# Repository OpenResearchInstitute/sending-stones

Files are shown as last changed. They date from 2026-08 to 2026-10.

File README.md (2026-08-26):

# Sending Stones

*The spell always works during a long rest. We measured whether it works in the tavern.*

Sending Stones is a delivery-ratio experiment for dense-event Meshtastic networks
such as found at amateur radio and computer security conferences. DC35 is the modeled
target for this implementation, but the experiment can be run at any dense event. 

Five identical matched-pair stations ("Stones") measure packet delivery ratio
with a known denominator. 

- `DESIGN.md` the experiment design (Rev B): domain model, hypotheses H1–H5,
  schedule, confound table, build plan
- `code/` station software: probe TX (slot scheduler + capture trials),
  RX monitor, collation
- `analysis/` **MAHALO** (*Mesh Assessment of Heard And Lost Offerings*),
  the analysis notebook
- `hardware/` BOM, station build details, bench/field notes (Phase 0–2)
- `data/` published trial datasets (post-con; node IDs salted-hashed per DESIGN §7)

Stations: Stone-FB Stone-RFV Stone-HRV Stone-CHILL Stone-COLD Stone of Reserve (spare)

License: GPL-3.0

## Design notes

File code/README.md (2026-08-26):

# Sending Stones, a delivery-ratio instrument for dense-event Meshtastic (Rev B)

Five identical stations. Each: Pi 4 + 2x Heltec V3 (cohort A: LongFast,
cohort B: ShortTurbo/event channel) + UPS-buffered AC. Role = config.yaml.

## Install (per station)
    sudo apt install python3-pip
    pip install meshtastic pypubsub pyyaml
    cp config.example.yaml config.yaml   # set station_id, slot, serial by-id paths
    python3 monitor_rx.py &              # always on
    python3 probe_tx.py &                # all stations transmit in Rev B

(systemd units recommended for deployment; run both under Restart=always.)

## Schedule model
- Minute cycle; station k owns seconds [12k, 12k+12).
- Normal probe: slot start + U(0,3) s jitter, per cohort, short/long payload
  alternating by seq parity. Probes never collide with each other by construction.
- H5 capture trial: every 10th minute, a ROTATING PAIR. Derived from the
  clock and the shared roster, no coordination traffic; all 10 pairs cycle
  every 100 min. Transmits at second 0 exactly (deliberate collision),
  alternating cohorts, flagged C. The other three stations listen.
  Optional 3-way trials behind a config flag (default off; Phase 2 gate).

## Post-con
    python3 collate.py stations/*.sqlite -o trials.csv
Produces trials.csv (H1–H4) + trials_h5.csv (capture trials), with
self-deafness excision and utilization covariates. Analyze in Python/MATLAB.

## Validated so far
- Payload build/parse round trip (short + long + capture flag + rejects garbage)
- End-to-end synthetic two-station run through collate.py recovers known
  injected loss rates within binomial error (n=30/path)

## Bench TODO (Phase 0, radio in hand)
- Confirm rx packet dict fields (hopStart/hopLimit, rxRssi) against current
  meshtastic-python version. We should adjust monitor_rx.on_receive if names drift
- deviceMetrics polling path for channelUtilization on local node
- Plug-yank UPS test under live logging
- Verify sendText targets primary channel on event firmware (cohort B)

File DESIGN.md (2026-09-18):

# Sending Stones
## Measuring What the Mesh Actually Delivers
## A Delivery-Ratio Experiment for Dense-Event Meshtastic Networks (DC35 target)

By Open Research Institute https://openresearch.institute

**Status:** Rev B is identical stations, all-TX round-robin, capture-effect trials added
**Motivation:** A LongFast vs. ShortTurbo debate at DEF CON 34 was argued from received-message counts observed at single points. This is a quantity confounded by population size, receiver aperture, and survivorship. No stage of any monitoring pipeline is known to have written to disk (will update this document if received). This design specifies the minimal sufficient instrument to measure packet delivery ratio (PDR) directly, at packet layer, with a known denominator.

---

## 1. Domain Model

**Station** This is the physical unit. One Pi 4 host, two Heltec V3 nodes (one per cohort), UPS-buffered AC power, matched antennas, one SQLite database. *All five stations are hardware-identical.* Role (whether/when a station transmits) is configuration, not hardware.

**Slot** Each station owns a fixed 12-second slot within every minute. Station k transmits at seconds [12k, 12k+12]. Slots guarantee our probes never overlap each other *by construction* except when we schedule them to do so, because reasons. (see Capture Trial).

**Probe** This is a packet we originate, identity is known before transmission. The packet communicates cohort, origin station, sequence number, and TX epoch. The set of all probes is the denominator. Probes transmit at slot start + U(0,3) seconds jitter. This jitter breaks any phase-lock with the population's periodic beacons. We do this because nodeinfo/position/telemetry fire on fixed intervals, and we want to avoid this. Slot boundaries keep probes from colliding with each other.

**Capture Trial (H5)** Hypothesis 5 is a *scheduled, deliberate* collision. Once every 10 minutes, two designated stations transmit simultaneously. This is on the same second, no jitter, same cohort. Which transmission each listening station decodes, versus the RSSI delta, measures LoRa capture behavior in the real world at the venue. This is the mechanism behind observations of surprisingly high utilization. We can run this experiment and get results without IQ capture. Capture-trial probes are flagged in the TX log and excluded from H1–H4 analysis. 

**Ambient load** This is the con's organic traffic. It is the independent variable the venue supplies. Characterized via device metrics (`channelUtilization`, `airUtilTx`) and logged continuously.

**Census** This is a 10-minute NodeDB snapshot per node. It is the lower-bound active-population estimate per preset over time.

**Trial** This is one (probe, listening station) outcome. We need to know whether a transmission was delivered or not. With 5 origins and 4 listeners, each cohort yields a 20-cell directed-path matrix. PDR for any slice = delivered/total in slice.

**Deafness accounting** A Meshtastic radio cannot hear during its own transmission. TX logs + slot table let `collate.py` excise each station's own transmit intervals from its listening record exactly. We can account for this. 

**Excluded by design:** IQ/PHY capture (Appendix A) and MQTT-side logging (samples only opted-in nodes)

---

## 2. Hypotheses

- **H1 (congestion regime):** PDR degrades as measured channel utilization rises and we should see a knee in the 25–50% region.
- **H2 (preset comparison):** Under matched offered load and matched apertures, ShortTurbo sustains higher PDR than LongFast in the dense regime, or does not.
- **H3 (aperture bias):** LongFast probes are received over longer paths than ShortTurbo probes. This quantifies how much single-point received-counts overstate LongFast.
- **H4 (multi-hop dies first):** PDR for hops ≥ 1 degrades faster with utilization than hops = 0. The capture-effect prediction is that relayed weak traffic starves out first.
- **H5 (capture effect, direct):** In scheduled simultaneous transmissions, decode outcome at each listener is predicted by RSSI delta. We can estimate the capture threshold (dB) per preset in-venue.

H3/H4/H5 are science and H2, in addition to being an engineering test, settles the questions raised on RF Village discord.

---

## 3. Experiment Design

### 3.1 Cohorts
| Cohort | Preset | Channel |
|---|---|---|
| A | LongFast | Default public primary (rides default-firmware population) |
| B | ShortTurbo | DC35 event channel (rides event-firmware population) |

Probes ride the **public** channels deliberately. PDR under ambient flood-rebroadcast load is the quantity in dispute. A private channel would share the RF but not the flooding behavior. Any event-specific firmware can be used in this experiment design for comparison. This experiment is not limited to the DEFCON-specific firmware build. The experiment works for any two firmware builds, as long as they are distinct enough, and the congestion or environment is differentiating enough, to enable an analysis of differences in the data.

### 3.2 Stations & geometry (DC35, LVCC + Fontainebleau as case study)
| # | Station | Location | Why |
|---|---|---|---|
| 0 | FB | Fontainebleau (off-site anchor) | "Reach my buddy across town" |
| 1 | RFV | RF Village, back of Hall 1, floor 1 | Dense, co-located with collaborators |
| 2 | HRV | Ham Radio Village, floor 3 | Vertical diversity — floor-to-floor paths force relaying |
| 3 | CHILL | Chill-out, floor 1 far end | Long same-floor path |
| 4 | COLD | TBD (Vendor area?) | Congestion epicenter; worst-case aperture |

Spare kit = slot 5, dormant; inherits a dead station's slot without schedule disruption.

### 3.3 Probe schedule (round-robin, aggregate-constant)
- Global minute cycle; station k transmits in its slot each minute, per cohort. Aggregate offered load: ~1 probe/min/cohort **per station**, 5/min/cohort network-wide, held constant regardless of station count by slot design. Airtime share verified post hoc against logged utilization (thermometer, not heat source).
- Payloads alternate short (~20 B) / long (~180 B) by seq parity. This means collision cross-section scales with airtime.
- Broadcast text (exercises flood routing). Optional low-rate DM probes for protocol-ACK cross-check.
- **Capture trials:** at minutes where epoch_min % 10 == 0, a rotating pair of stations transmits at second 0 exactly, no jitter, same cohort, flagged C. The pair is derived from the clock and the shared station roster. Every station computes the schedule independently, so no coordination traffic rides the channel under test. All 10 pairs cycle every 100 minutes. The other three stations listen.
- Duration: Thu 10:00 to Sun 14:00, continuous.

### 3.4 Timing
Pi hosts NTP-synced (GPS/PPS optional). Required resolution is modest. Slot alignment needs hosts within ±1 seconds. Drift is logged.

### 3.5 Power
AC-primary, battery-buffered at every station. We use a quality 5.1 V wall brick, a UPS layer (Pi UPS HAT w/ 18650s, or empirically verified pass-through bank), and this supports the Pi. Bench acceptance test is yank wall power under live logging and any reboot results in a fail. Battery voltage logged to `events` where HAT writes I2C telemetry. Village staff at DEFCON reports hall power stays on overnight and we treat this as a planning assumption to be verified on site. Your site may duck power at night. There can be outages. This design ensures data collection continues during power outages.

### 3.6 Confound table
| Confound | Response |
|---|---|
| Population differs per preset | Census; PDR is population-independent for probes |
| Aperture differs per preset | Co-located matched RX per station; H3 measures it |
| Probes perturb network | Slot budget + post-hoc airtime share check |
| Probe–probe interference | Slots (never overlap except scheduled H5 trials) |
| Phase-lock with ambient beacons | In-slot jitter U(0,3) s |
| Self-deafness | TX-log-driven excision in collate |
| Node/antenna variance | Identical SKUs, pre-con common-TX calibration hour, per-node RSSI offsets recorded |
| Hop-limit differences per firmware | Hop count recorded per RX and PDR conditioned on hops |

---

## 4. Hardware is Five Identical Station Kits (+1 spare)

### 4.1 Station host: Raspberry Pi 4 (decision record)

The host has four jobs. First, speak the Meshtastic serial protocol. Second,
make durable timestamped writes for four days. Third, keep true time 
(±1 s slot alignment), and finally, allow remote login (SSH), so a wedged 
station can be diagnosed and restarted from anywhere in the venue instead of 
requiring a physical visit.

**Pi 4 Model B (2 GB)** does all four with zero custom engineering. 
The official `meshtastic` Python library (project-maintained against
firmware protobuf drift), SQLite/WAL on a journaling filesystem, chrony over
Ethernet or GPS, and SSH. Four native USB-A ports take both radios directly.

Roads considered and not taken:
- **Pi Zero 2 W + USB hub** It has one port and a hub adds a fourth vendor's 
  firmware to the serial path and an enumeration-order failure class. 
  Rejected: buys $27/station at the cost of the most annoying bug family in 
  embedded Linux. Really don't want to deal with this. YMMV.
- **GPIO hardware UARTs** This is deceptively elegant, but trades the hub for 
  soldered harnesses and loses reflash-over-cable. Complexity relocated, not 
  removed.
- **WiFi/TCP to the radios** This puts the instrument's control plane on 2.4 GHz
  at DEFCON. Hm. It adds RF activity, attack surface, and dependency on the most
  hostile network environment in North America. Serial cables don't suffer as much.
  Wired is indoor plumbing. Wireless is an outhouse. Let's go with indoor plumbing.
- **ESP32 as host** So this requires reimplementing the protocol client, crash-safe
  logging on FatFS/SD which is not easy, and it means timekeeping without
  RTC/NTP. Converts ~$30/station into a firmware subproject on the least interesting 
  layer. YMMV. Correct platform for a *future* low-power rural derivative.
- **Custom logging firmware on the Heltecs themselves** So very disqualifying. This
  is not just expensive. It changes the device under test. Stock radio firmware is
  a design invariant. This is really important. Logging intelligence must
  therefore live in a separate host. Don't modify the device under test.

### 4.2 Kit contents

Per kit we have 

1× **Pi 4 Model B (2 GB)** + official 5.1 V/3 A USB-C PSU
2× **Heltec V3** (deliberately V3, not V4: the V3 *is* the deployed population at the most popular, and 28 dBm V4 beacons would punch through collisions that eat everyone else's packets, biasing PDR optimistic. V4 firmware also currently disables RX preamp in sleep which doesn't work for us)
1× Pi-4-class UPS HAT + 18650s (plug-yank tested)
1× high-endurance 32 GB microSD
2× TE/Linx ANT-916-CW-HW-SMA half-wave dipoles

Sourcing: 

Radios from Rokland (single controlled lot) or Heltec direct; **confirm US915 variant per unit at bench**. 
Pi 4s from CanaKit/PiShop/Adafruit. Full parts list, sources, and intake checklist: **hardware/BOM.md**. 
Antennas/pigtails from Digi-Key
SD/power from B&H.

Firmware: stock Meshtastic release (cohort A), stock DC35/event firmware (cohort B). All nodes get fixed position on, GPS off, MQTT off, BT off after config, telemetry intervals left at that firmware's defaults (matching the measured population).

Budget: ~$1,000–1,100 all-in (6 kits + bench mules + field kit). See BOM for final budget.

---

## 5. Software

One golden SD image set to role = YAML. Every Pi runs `monitor_rx.py` always; `probe_tx.py` runs everywhere too (all stations transmit), parameterized by slot. 

Code layout:

```
code/
  config.example.yaml   station id, slot, serial ports, schedule, capture-trial config
  db.py                 schema + writer helpers (WAL mode)
  probe_tx.py           slot scheduler, probe + capture-trial TX, tx_log
  monitor_rx.py         RX logging, probe parsing, census, utilization, events
  collate.py            multi-station join → trials table (CSV/Parquet) + PDR summary
```

Schema additions vs. Rev A: `tx_log.is_capture`, `rx_log.is_capture`, slot table embedded in config, `events.kind` includes `power`, `timesync`, `serial_gap`. This gets us everything we need.

Probe payload: `PDR|<cohort>|<station>|<seq>|<epoch>|<N/C>` padded to target length. Announced on con channels (etiquette + free decode documentation).

There could be Easter Eggs or a CTF in the probes if we want. If this is done, egg content must live after the flag. It can be in the padding field or additional pipe-delimited fields. Do not put it inside the first six.

---

## 6. Analysis Plan (pre-registered)

Primary: PDR(cohort, path, hour), Wilson 95% confidence intervals. Round-robin note: per-origin rate is 1/min, so per-path trials ≈ 60/hr before exclusions; pool 2–4 h windows narrows it down to ±4–6% confidence intervals.

1. H1: PDR vs. binned `ch_util`, per cohort. Find the knee.
2. H2: paired PDR difference (B − A) per station-hour, with intervals.
3. H3: delivery vs. path class (same-floor / cross-floor / off-site) per cohort; ambient RX-distance distributions.
4. H4: PDR × hops(0, ≥1) × utilization, per cohort.
5. H5: logistic fit of decode outcome vs. RSSI delta per listener leads to capture threshold estimate (dB) per preset.
6. Descriptives: census curves, our airtime share (honesty check), gap/annotation audit.

Deliverables: A QEX-shaped write-up + raw trials + code, open-licensed. DC34's negative space (largest known mesh, no or limited logs) is the introduction.

---

## 7. Ethics, Legality, Etiquette
ISM band, stock power, budgeted duty cycle, reported airtime share. Third-party payloads **not retained** (metadata only: port, size, from-id, RF stats); node IDs salted-hashed in the published set. Village coordination in advance. Live PDR readout offered as village display. Probe format announced on-mesh.

## 8. Build Plan
| Phase | What |
|---|---|
| 0. Bench (San Diego) | 1 full kit; TX/RX round-trip; plug-yank UPS test; schema locked |
| 1. Field (San Diego) | 3 kits across town. This incidentally yields a sparse-rural baseline (the "range matters more" home regime) as published contrast data |
| 2. Load rehearsal | Club event / hamfest; census + utilization capture verified (let us know if you want to have this at your event)|
| 3. Freeze | Code freeze; event-firmware flash/recover drill; pack list |
| 4. Deploy | DC35 Thu AM; daily SD swap + timesync check |
| 5. Analyze | collate then go to notebook then go to write-up then publish|

## 9. Synchronized Multi-Aperture Reception Survey
N identical passive monitoring stations (CLIENT_MUTE, LongFast, UTC-synchronized) 
deployed at geographically-distinct apertures across the San Diego–LA region, 
logging concurrently. Because all stations observe the same channel over the same 
interval, cross-aperture comparison isolates the effect of siting and geography 
on reception. The union of receptions across stations approximates ground-truth 
transmission activity, enabling per-aperture delivery-fraction estimates that a 
single station cannot produce. We did this with one station and it's in mahalo-2.

## 10. San Diego Field Trial, Full-Experiment Dress Rehearsal

**Purpose.** Run the *complete* Sending Stones PDR experiment across San Diego–region
apertures **before DEFCON**, configured identically to the DEFCON deployment, so that the
first time the full system runs is at home, where a failing station is a drive away and not on
a con floor where it will suck to fail.

This is **not** a passive characterization survey (that is MAHALO-2, already done for one
aperture). This is the real experiment setup. Stations transmit scheduled probes, receive each
other's probes, run collision trials, and log to per-station databases that collate into a
delivery-ratio dataset. San Diego is the rehearsal and DEFCON is the performance.

---

## Why a full rehearsal is necessary and what has never run

Everything below is currently **unexercised** and must not debut at DEFCON (Update as we go!)

- **`probe_tx.py` has never transmitted a probe that another station received.** The transmit
  path, the payload format, the slot scheduler, validated only in isolation, never end-to-end
  over the air to a second station.
- **The slot-synchronized rotation has never run across stations.** The clock-derived slot
  assignment (station k transmits in seconds [12k, 12k+12) of each minute) assumes all stations
  share UTC and compute the same schedule independently. Never tested with >1 transmitter.
- **The capture-trial collision machinery (H5) has never fired.** Scheduled simultaneous
  transmission by clock-derived rotating pairs and this is pure theory until two stations 
  actually collide on purpose and a third records it.
- **`collate.py` has never run on real distributed multi-station data.** Cross-joining probes
  against receptions across stations, excising self-deaf intervals, attaching the utilization
  covariate. It has been tested on synthetic 2-station data only.
- **Multi-station Tailscale fleet management has never been exercised.** Reaching, monitoring,
  and pulling data from N stations concurrently. Proven for one (Palomar) and untested at fleet scale.

The field trial exists to make all of these fail *here*, cheaply, before they can fail expensively.

---

## Station configuration is identical to DEFCON

Every field-trial station is a **full experiment participant**, configured exactly as it will be
at DEF CON:

| Setting | Value | Rationale |
|---|---|---|
| Role | **CLIENT** (not CLIENT_MUTE) | Must transmit probes and receive; muting breaks the experiment |
| `tx_enabled` | **true** | Stations run `probe_tx.py` and send scheduled probes |
| Rebroadcast | **decision required - see below** | Whether probe stations also relay ambient traffic |
| Preset (cohort A) | LongFast | Matches the deployed population |
| Preset (cohort B) | ShortTurbo | The comparison arm (H2) needs the second radio per station |
| Timezone | UTC | Slot synchronization depends on shared clock |
| Time source | NTP + on-board RTC | Slot timing must not drift; RTC backs NTP across brief outages |
| `station_id` | per station (FB/RFV/HRV/CHILL/COLD…) | Identity in probe payloads and collation |
| `slot` | 0..N-1, unique per station | Round-robin TX schedule |
| Tailscale | on, tested | Remote management of the whole fleet |
| Logger | `monitor_rx.py` (validated: replay-gated, from_id, threading) | RX side |
| Transmitter | `probe_tx.py` | TX side **first real multi-station run** |

### Open decision: do probe stations also relay?

- **Relay ON** stations behave as normal mesh nodes (participate in flooding). Measures PDR as
  a *real participating node* experiences it; most realistic. Cost: your stations add relay load
  and become part of the ambient traffic you're measuring against.
- **Relay OFF (rebroadcast NONE), probe-TX on** stations inject only their own known probes and
  receive everything, but do not rebroadcast others'. Cleaner isolation of the controlled signal;
  your fleet doesn't amplify the background. Recommended for the *cleanest PDR measurement*.

**Recommendation:** relay OFF for the primary PDR arm (measure delivery of a clean injected
signal), with the option to run a relay-ON block separately to compare "participant PDR" vs
"injected-signal PDR." Decide and record before deployment; do not leave it to per-station default.

---

## Radios are the gating dependency

The full experiment needs **two radios per station** (cohort A LongFast + cohort B ShortTurbo)
to run the H2 preset comparison. With ~10 radios inbound:

- **5 stations × 2 radios = 10** this means the full five-station, two-cohort experiment. This is the target.
- If fewer are usable at trial time: run **single-cohort (LongFast only)** across as many stations
  as radios allow. A 3-station single-cohort trial still exercises probe TX/RX, slot sync, capture
  trials, and collation (the untested machinery) even without the preset-comparison arm. Do not
  wait for all ten to start; a reduced trial de-risks most of the system.

Stone Cold (Palomar) currently holds the one flashed radio as a passive monitor. When the fleet
radios arrive, either reflash/repurpose it into the trial or leave it as an ongoing passive
baseline and build the trial from new radios and decide based on count.

---

## Sites and the aperture geometry

The trial's scientific value is in *aperture diversity*, so sites should span the
range/geography axis, not cluster. Target profile:

- **Palomar Mountain** is high rural, wide aperture (proven: 568 nodes/24h). The long-range anchor.
- **Carmel Valley** is suburban San Diego, mid aperture. The "typical deployment" point.
- **Long Beach** is dense urban, LA basin, ~150 km north. House-hosted (reliable power/network/hands).
  Tests whether the mesh bridges SD to LA at all, and gives a genuinely different urban aperture.
- **1–2 more San Diego points** we need to fill in the geometry (e.g., a coastal site, a central-city site).
  Maybe a library or school would help. 

Each site needs: a willing host, AC power, and network (WiFi or ethernet). The Palomar deployment
proved the bring-up template (power, network, Tailscale, validated code, launch), so each new
site follows the STATION-SETUP.md checklist.

**Note on the SD to LA span:** at ~150 km, Long Beach almost certainly cannot hear San Diego nodes
directly. That distance exceeds even Palomar's reach. That is itself a *measurement*: the trial
quantifies the geographic extent of mutual reception, and likely shows San Diego and LA as
*distinct mesh regions* with limited or no direct bridging. Whether any node is heard by both a
San Diego station and Long Beach is an empirical question the trial answers.

---

## What the trial measures (the science, beyond de-risking)

1. **Per-aperture, per-preset delivery ratio (H2).** For known transmitted probes, what fraction
   does each station receive, on LongFast vs ShortTurbo? The core PDR question, with a real
   denominator (probes are counted at TX).
2. **Cross-aperture reception maps.** Which stations heard each probe gives indication of coverage 
   overlap and gaps between apertures.
3. **Capture-effect under scheduled collisions (H5).** When two stations transmit simultaneously,
   what does a third receive? First real data on LoRa capture in this setting.
4. **The consensus denominator, cross-checked.** The union of receptions across stations vs. the
   known TX ledger validates the "spatial diversity as denominator" method against ground truth
   you actually have (because you control the transmitters).
5. **Aperture geography.** The extent and boundaries of mutual reception across the SD to LA region.

---

## Success criteria for the rehearsal (de-risking checklist)

The trial has done its job when all of these have happened *at least once, in San Diego*:

- [ ] A probe transmitted by one station is logged as received by another (probe TX/RX round-trip).
- [ ] All stations independently compute and transmit in the correct slot (schedule sync holds).
- [ ] A capture trial fires: two stations transmit simultaneously, a third logs both/one/neither.
- [ ] `collate.py` produces a delivery-ratio table from real multi-station databases.
- [ ] The full fleet is reachable and its data pullable over Tailscale concurrently.
- [ ] A station survives a multi-day run unattended (endurance, already shown for one; confirm for fleet).
- [ ] At least one deliberate failure (unplug a station) is detected and recovered/logged cleanly.

Every box checked in San Diego is a box that will not be checked for the first time at DEFCON.

---

## Sequence

1. **Now (radios in transit):** secure sites (hosts, power, network); finalize the relay-on/off
   decision; keep Palomar passive baseline running.
2. **Radios arrive:** flash (region US, cohorts A/B per station), apply STATION-SETUP.md per box.
3. **Deploy** to secured sites; bring each up via Tailscale; verify i2c/power/network/logger.
4. **Bench the probe round-trip first** with two stations on one bench, confirm `probe_tx.py` gives
   `monitor_rx.py` logs a probe, before distributing. (This is the single most important untested
   step; do it before driving anywhere.)
5. **Run the distributed trial** this is a synchronized, multi-day, full experiment.
6. **Collate and analyze** goes to MAHALO-3, and a proven system for DEF CON.

## FINDING
Bench, 14 September 2026: monitor_rx.py and probe_tx.py each work in isolation but CANNOT run simultaneously. Serial ports are exclusive, and each opens its own SerialInterface. Unify into a single per-station process (station.py) that opens each radio once and runs both the RX subscription and the TX scheduler against the shared interface. This is a prerequisite for any real PDR measurement. Issue was opened. 

## FINDING
Bench, 14 September 2026 (frequency behavior verified by radio config, same date):

Two environments, two questions. The field trial spans two fundamentally different RF environments, and it is important not to confuse what each can measure.

San Diego (light load). The deployed San Diego population is ~99% LongFast. Measured directly: a co-located dual-cohort station heard 247 distinct LongFast nodes versus 2 ShortTurbo nodes over 16 hours. This installed-base asymmetry has two consequences. First, cohort A (LongFast) participates in a real, populated network, while cohort B (ShortTurbo) is nearly alone. Its logs are dominated by the fleet's own probes because almost no ambient ShortTurbo traffic exists to receive.

Second, the two cohorts are not on the same frequency. Presets are not merely different modulation schemes on a shared channel. In Meshtastic's default configuration (channelNum=0, auto), the operating frequency is derived from a bandwidth-dependent division of the band. LongFast (250 kHz bandwidth) and ShortTurbo (500 kHz bandwidth) divide the US band into different numbers of slots (~104 vs ~52), so the same channel name computes to different center frequencies. The two cohorts therefore occupy different, separately-populated slices of spectrum. They neither decode nor significantly interfere with each other. This is confirmed by measured utilization. Cohort A's frequency runs 8–39% utilized (the LongFast population), while cohort B's frequency reads ~0% (almost no deployed ShortTurbo users). Practical consequences are that a station's own A and B radios do not self-interfere, so simultaneous dual-cohort operation from one station is clean, and cohort B's probes are not contended by LongFast traffic, because that traffic is on a different frequency. ShortTurbo genuinely gets a quiet slot, but not because presets are isolated by protocol, but because the auto-frequency mechanism places them on different frequencies with different populations.

What San Diego can measure, then, is propagation, range, and cross-aperture reception under light load. Like, how far and how reliably probes travel between separated apertures (Palomar, Carmel Valley, Long Beach) on each preset. Plus the installed-base asymmetry itself, which is a real finding. Anyone saying "LongFast outperforms ShortTurbo" comparison is dealing with not only by LongFast having vastly more peers, but also by the two presets sitting on differently-loaded frequencies. What San Diego cannot measure is congestion effects, because its channel is not saturated when logging from a suburb. The 247 LongFast nodes are mostly distant, low-duty-cycle beacons, not a collision-inducing load.

DEF CON (heavy load). The congestion question, where ALOHA/backoff regime where preset choice under a saturated channel actually matters, becomes measurable only where utilization approaches the collision knee, which requires the density of a large event. This is precisely the environment the San Diego field trial cannot replicate and DEF CON provides. There, cohort A and cohort B probes contend with genuinely loaded frequencies, and the delivery difference reflects how each modulation fares under congestion. But note the problems that we have in San Diego do not vanish at DEFCON. they get more problematic. An A-vs-B delivery difference mixes (1) modulation robustness, (2) the two cohorts' different center frequencies, and (3) the different populations/loads on those frequencies. These cannot be fully separated in the wild, because the deployed base fixes LongFast to a busy frequency and ShortTurbo to a sparse one. What DEF CON adds is that both frequencies **may** become loaded enough for congestion to bite. So the comparison is at least "congested vs congested" rather than "busy vs empty." What we are depending on is having something to compare default configurations **against**. Cohort B needs to be something interesting, such as DEFCON-specific firmware. 

**Scope, stated plainly.** The San Diego trial de-risks the experiment machinery and characterizes propagation, range, and installed-base/spectrum-occupancy asymmetry across apertures under light load. The congestion hypotheses (H1, the utilization knee; H2, the preset comparison under load) are DEFCON measurements. Two errors we need to avoid: treating San Diego's light-load results as congestion evidence; and treating any A-vs-B difference as a clean preset-merit comparison, when it is always complicated by the cohorts' different frequencies and different populations. Treating San Diego's results as range/propagation/installed-base evidence is exactly right, and is what we will do until a dense event lets us probe congestion directly.

## FINDING
Bench, 17 September 2026 

Problem resolved! (durable): station.py resumes seq from the database on restart (Fix 1) and uses a plain INSERT with loud collision logging instead of silent OR-REPLACE (Fix 3). Restarting a station mid-capture no longer wrecks tx_log data. The seq continues monotonically, and any impossible collision is logged and skipped rather than overwriting. Restart is a lot safer. The earlier "don't restart mid-capture" caveat is now gone. 

## Appendix A: Why not IQ?
PHY capture answers *why* packets die, at 100–1000 GB/station + SDR/DSP pipeline. 
Delivery ratio needs a known numerator/denominator at packet layer. The nodes 
provide it directly. H5 recovers the headline capture-effect result at the packet 
layer for free. IQ is the sequel, contingent on these results.

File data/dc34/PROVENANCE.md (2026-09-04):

# PROVENANCE for DEF CON 34 Contributed Captures (public version)

**Status:** Published 2026-09. Collectors are anonymized pending their consent;
this file will be updated with credit as contributors opt in.
**Location of data:** NOT in this repository, at the contributors' request.
This file documents what the captures are, what each instrument can and cannot
see, and integrity fingerprints for verifying a privately-shared copy. The
derived analysis (aggregates only) is `analysis/mahalo-1-dc34/`.

---

## Policy

1. **Attribution by consent.** Collectors are named only if they choose to be.
   Roles are used until then. Credit is offered, never imposed.
2. **Field semantics are collector-specific.** No field is interpreted until
   verified against the collecting tool. Two corrected errors in MAHALO-1
   came from this rule (`hop start = 0` ≠ zero hops; `hops_away` = budget
   remaining, not traveled).
3. **Dedup behavior is part of the instrument.** Whether a capture preserves
   duplicate receptions determines which phenomena it can see at all.
4. **Raw data is not republished; fingerprints are.**
5. **No identifiers in derived artifacts.** Node IDs render as rank labels;
   sender names, payloads, and collector file paths are never rendered.

---

## Chain of custody

All artifacts were shared privately with Open Research Institute on 2026-08-26
by a community member acting as intermediary for the collectors. The
intermediary requested that datasets not be republished; that request is
honored here. Collectors have been offered review and credit.

---

## Artifacts

### A. App-level datalog (CSV, 39,837 rows)
- **Instrument:** Meshtastic app/serial datalog export from a single node.
- **Position:** unknown (con-floor class aperture inferred from traffic shape).
- **Coverage:** Aug 5–11 local time; **no timezone recorded**.
- **Dedup behavior:** app-level, one row per unique packet.
  **Structurally blind to duplicate-reception phenomena** (the storm class).
- **Fields:** no packet ID, no destination; SNR on all rows.
- **Fingerprint (SHA-256 prefix):** `071f9b2cb0cf`

### B. Device-trace megalogger database (SQLite, 814,441 records)
- **Instrument:** trace-log tailer with resume-safe cursors and per-line
  SHA-256; every RF reception retained, including encrypted (header-only)
  packets (~97% of records).
- **Position:** high-elevation aperture, upper floor of a north-Strip hotel.
- **Coverage:** 2026-08-03 15:46 → 08-09 17:34 **UTC** (verified via
  human-diurnal TEXT traffic, MAHALO-1 §2.2).
- **Dedup behavior:** ingestion-level only; **RF duplicates preserved** — the
  instrument that made the storm class visible.
- **Verified semantics:** `hops_away` = hop budget remaining; zeroed
  timestamps excluded (`> 1e9`); channel hash 209 = its decodable primary;
  storm traffic rode hashes 14 and 0 (undecrypted at this aperture).
- **Fingerprint:** `c2376cc4e92e`

### C. SDR PHY-layer capture (49 files)
- **Instrument:** `lorarx` demodulator, parallel SF7–SF11 decoders on 500 kHz
  windows; per-frame measured airtime, SNR, level, CRC status, raw LoRa frame.
  Sync-word filter off, captures **all** in-band LoRa. Frames require
  classification.
- **Frequencies:** 906.875 MHz (LongFast slot), 917.250 MHz, 910.525 MHz.
- **Position:** a different Strip property from B, ~1 km distant.
- **Coverage:** filenames carry capture-start time only; rows have **no
  absolute time**. Bulk of material Sunday 2026-08-09.
- **Dedup behavior:** none (raw stream); cross-SF double-decodes possible.
- **Pending verification:** CRC field semantics (three-state 0/1/−1 observed).
- **Fingerprints:** per-file prefixes recorded in artifact D's `merge_sources`.

### D. Merged database (SQLite, 2.8 GB)
- **Instrument:** engineered merge of A, B, C, and E. Profile
  `defcon34-conservative-v1`. Not an independent capture.
- **Dedup design:** every observation retained with a disposition
  (1,603,700 observations; 890,601 canonical) dupes adjudicated, not deleted.
  Per-source clock and identity bases recorded rather than normalized.
- **Limitations:** trace layer ≈ B + C rows (not independent corroboration of
  B-derived findings); C rows lack IDs and absolute time, so the conservative
  matcher joined **zero** keys between B and C, cross-aperture nulls from
  this merge are instrument limitations, not evidence.

### E. Broker-side infrastructure export
- **Instrument:** MQTT broker configuration, MQTT→Postgres collector, packet
  export (58,323 rows), viewer history databases (59,194 / 12,132 rows).
- **Aperture:** server-side view of gateway-connected traffic only. Near-blind
  to the storm class, which made it the decisive falsification instrument
  for the gateway-re-injection hypothesis (MAHALO-1 §4.2).
- **Note:** the export includes operational configuration not suitable for
  redistribution; the operator has been notified through the intermediary.
  Only aggregate row counts are used here.

---

## What these captures cannot provide
A delivery ratio. No offered load was controlled because no denominator exists.
Characterizing what was *heard* is the ceiling of retrospective analysis.
Measuring what is *delivered* is the Sending Stones experiment (`DESIGN.md`).

## Contributors
Anonymized pending consent. To claim credit for any artifact, or to request
changes, open an issue or contact ORI. Credit will be added on request.

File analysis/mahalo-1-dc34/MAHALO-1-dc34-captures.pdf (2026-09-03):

# MAHALO Notebook 1

# What the DC34 Captures Reveal

## Mesh Assessment of Heard And Lost Offerings

by Abraxas3d for Open Research Institute, Inc.

Sending Stones project https://github.com/OpenResearchInstitute/sending-stones

Open Research Institute https://openresearch.institute

Graciously enabled by Vid through RF Village Discord (thank you!)

Inputs (local only, never republished): per contributor request, the datasets analyzed here are not distributed with this notebook. Paths below point at local copies. This notebook renders only aggregates. Counts, histograms, and time series. Node identifiers appear only as anonymous rank labels (S1, S2, ...). Sender names and message payloads are never selected into memory. What this accomplishes is that personally-identifiable informatin (PII) is kept private by construction.

Node identifiers are rendered as rank labels (S1–S10) rather than raw device IDs, to avoid attributing specific behavior to identifiable devices. Collector handles and capture locations are retained as contributor credits.

Provenance (to be completed as confirmed):

Capture | Collector | Position | Instrument | Coverage
a5fe CSV | unknown
(node | …
a5fe | )
| | unknown (con floor?) | app/serial datalog, deduplicated by packet | Aug 5–11

feeb-fb31.db

"Feeb"

Fontainebleau,
31st floor

megalogger (device trace tail → SQLite), duplicates
preserved

Aug 3–9

Headline caution, pre-registered: none of these captures contains a delivery ratio. No offered load was controlled, so no denominator exists. Everything here characterizes what was heard at specific apertures and not what was delivered. Sending Stones
controls an offered load, therefore the experiment will produce a denominator.

# ---- Parameters: edit paths for your machine ----

A5FE_CSV = "Meshtastic_datalog_a5fe_20260811_144102.csv" # Blue-Palace: ~/M
FEEB_DB = "feeb-fb31.db" | # Blue-Palace: ~/M
STORM_THRESHOLD = 15 | # copies; > N defines the pathological ("storm") clas In [1]:

import os, sqlite3
import pandas as pd, numpy as np
import matplotlib.pyplot as plt plt.rcParams.update({"figure.figsize": (9, 3.2), "figure.dpi": 110}) HAVE_FEEB = os.path.exists(FEEB_DB)
print(f"a5fe: {os.path.exists(A5FE_CSV)} | feeb: {HAVE_FEEB}")
a5fe: True | feeb: True
1 Aperture A: the | a5fe | app-level datalog

A single node's log, app-deduplicated (one row per unique packet heard). Columns kept: timestamps, numeric sender id, port tag, hop fields, SNR. Not loaded: sender names, payload text.

# What columns are we going to use

usecols = ["date","time","from","rx snr","hop limit","hop start","payload"] a = pd.read_csv(A5FE_CSV, usecols=usecols)
a["ts"] = pd.to_datetime(a["date"] + " " + a["time"])
# port tag only; drop payload text immediately

a["port"] = a["payload"].str.extract(r"^<([A-Z_]+)>")[0].fillna("TEXT/other" a = a.drop(columns=["payload","date","time"])
print(f"rows={len(a)} span={a.ts.min()} to {a.ts.max()} unique senders={a[

rows=39837 span=2026-08-05 22:50:33 to 2026-08-11 14:41:06 unique senders= 2123

fig, ax = plt.subplots(1, 2, figsize=(11, 3.2)) a.groupby(a.ts.dt.date).size().plot(kind="bar", ax=ax[0], color="#456990") ax[0].set_title("a5fe: packets heard per day"); ax[0].set_xlabel("") a["port"].value_counts().plot(kind="barh", ax=ax[1], color="#456990") ax[1].set_title("a5fe: port mix (protocol overhead vs text)") ax[1].invert_yaxis(); plt.tight_layout()
ov = a["port"].isin(["NODEINFO_APP","TELEMETRY_APP","POSITION_APP","ADMIN_AP print(f"protocol housekeeping share: {ov:.0%}")

protocol housekeeping share: 75%

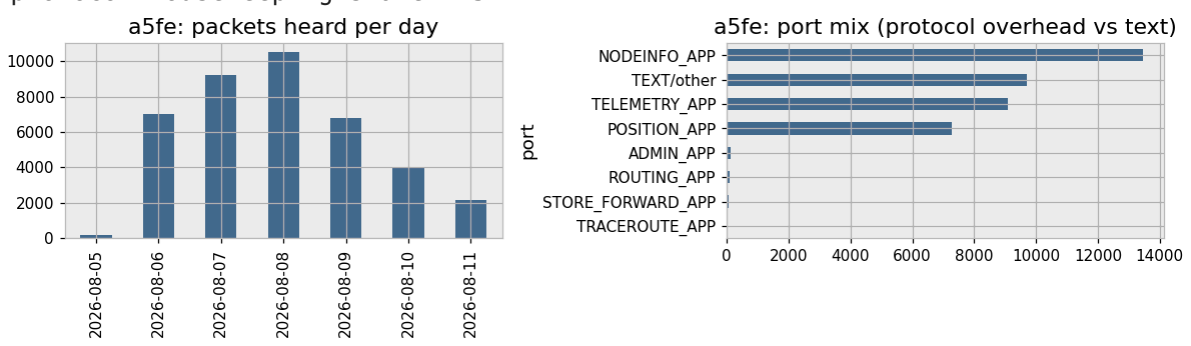
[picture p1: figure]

Parser doctrine #1 (learned here): rows where | hop start == 0 | mean unknown
hops (older firmware doesn't populate the field), and not zero hops. Computing hop_start − hop_limit without that filter manufactures a phantom “−4 hops” population. Ask me how I know :D

# In [2]: In [3]:

h = a[a["hop start"] > 0]
hops = (h["hop start"] - h["hop limit"])
axh = hops.value_counts().sort_index().plot(kind="bar", color="#456990") axh.set_title("a5fe: hops traveled (hop_start>0 rows only)"); plt.tight_layo print(f"known-hop rows: {len(h)} of {len(a)}")
print(f">=4-hop share of known: {(hops>=4).mean():.1%}")
print(f"event firmware capped 3, so 4+ is default-firmware flood behavior")

known-hop rows: 26736 of 39837
>=4-hop share of known: 21.4%
event firmware capped 3, so 4+ is default-firmware flood behavior

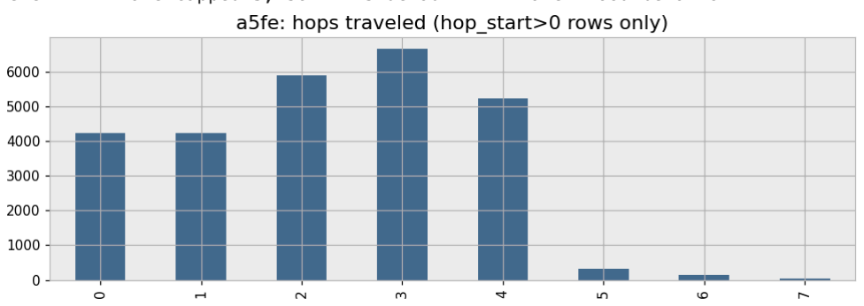
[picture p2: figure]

2 Aperture B: | feeb-fb31.db | (Fontainebleau 31st

# floor, duplicates preserved)

This is a tailing logger with resume cursors and per-line SHA-256. Crucially, every RF reception kept, including encrypted traffic (headers only decode). ~97% of receptions are header-only. They are countable and joinable but unreadable. This cleanly separates flood physics from message privacy. All cells below no-op gracefully if the database path is absent.

def q(sql):
if not HAVE_FEEB:
print("feeb db not present; skipping"); return pd.DataFrame() with sqlite3.connect(FEEB_DB) as cx:
return pd.read_sql_query(sql, cx)

counts = q("""SELECT 'records' k, COUNT(*) n FROM trace_records
UNION ALL SELECT 'raw', COUNT(*) FROM trace_raw_packets
UNION ALL SELECT 'decoded', COUNT(*) FROM trace_decoded_packets""") census = q("SELECT COUNT(DISTINCT from_node) n FROM trace_raw_packets") print(counts.to_string(index=False))
if HAVE_FEEB: print(f"unique senders heard: {census.n[0]}")
k | n
records 814441
raw 789041
decoded 25400

# unique senders heard: 2782 In [4]: In [5]:

daily = q("""SELECT date(trace_timestamp,'unixepoch') d, COUNT(*) n
FROM trace_raw_packets WHERE trace_timestamp > 1e9 GROUP BY 1 ORDER BY 1""") if len(daily):
daily.plot(x="d", y="n", kind="bar", legend=False, color="#7a3b46") plt.title("FB31: receptions per day (note Thu–Sat looks more like a plat plt.xlabel(""); plt.tight_layout()

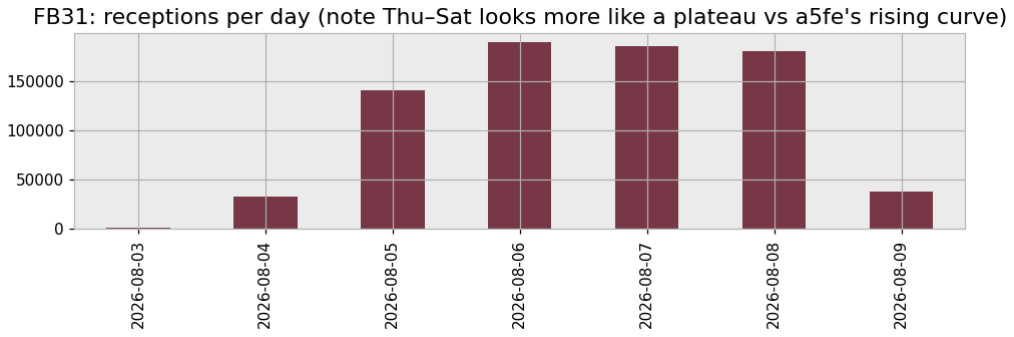
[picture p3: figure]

## 2.1 Flood duplication & the storm class

(from_node, packet_id) | is a global packet identity. Copies-per-packet measures
flood fan-out at this aperture. The | hop_start == hops_away | signature marks
receptions arriving with full budget. I claim this means that they were heard directly from an originator. Thousands of full-budget copies of a single packet id mean the same packet was re-originated at machine rate (retry storm and/or MQTT gateway re-injection), and not merely relayed.

cp = q("""SELECT n_copies, COUNT(*) n_packets FROM
(SELECT from_node, packet_id, COUNT(*) n_copies FROM trace_raw_packets GROUP GROUP BY 1 ORDER BY 1""")
if len(cp):
plt.loglog(cp.n_copies, cp.n_packets, marker=".", ls="none", color="#7a3 plt.axvline(STORM_THRESHOLD, color="gray", ls="--", lw=1) plt.title("FB31: copies heard per unique packet (log–log) and dashed lin plt.xlabel("copies"); plt.ylabel("packets"); plt.tight_layout() storm_share = q(f"""SELECT 1.0*SUM(c)/(SELECT COUNT(*) FROM trace_raw_pa (SELECT COUNT(*) c FROM trace_raw_packets GROUP BY from_node, packet_i HAVING c > {STORM_THRESHOLD})""")
print(f"share of ALL receptions belonging to >{STORM_THRESHOLD}-copy pac

share of ALL receptions belonging to >15-copy packets: 69%

# In [6]: In [7]:

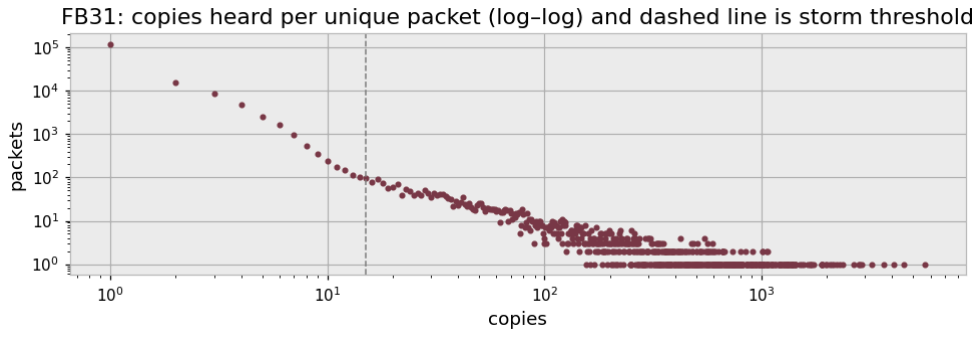
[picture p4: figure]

cp2 = cp.sort_values("n_copies").copy()
cp2["receptions"] = cp2.n_copies * cp2.n_packets cp2["cum_share"] = cp2.receptions.cumsum() / cp2.receptions.sum() below = cp2[cp2.n_copies <= STORM_THRESHOLD].cum_share.iloc[-1] plt.figure()
plt.semilogx(cp2.n_copies, 100*cp2.cum_share, color="#7a3b46") plt.axvline(STORM_THRESHOLD, color="gray", ls="--", lw=1, label=f"storm threshold ({STORM_THRESHOLD} copies)") plt.axhline(100*below, color="gray", ls=":", lw=1, label=f"{100*below:.0f}% of receptions ≤ threshold") plt.legend(loc="lower right")
plt.xlabel("copies per packet (≤ x)"); plt.ylabel("% of all receptions") plt.title("FB31: cumulative share of receptions by packet copy-count") plt.tight_layout()

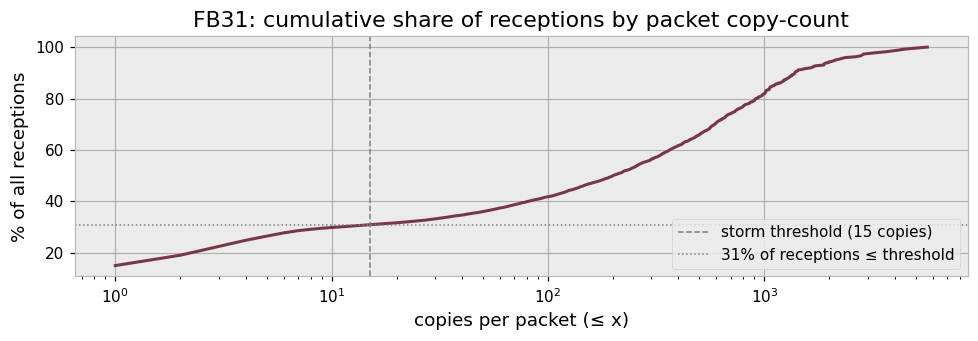
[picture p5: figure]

## What do these plots show?

Both plots show all the packets. The dashed line is a fence. The storm class is everything to the right of the fence. The normal mesh is everything to the left. Neither plot filters. They show the whole distribution and let the threshold partition it visually. The log–log plot shows where packets live along the copy-count axis. The cumulative plot shows where the receptions pile up.

Is this a bad storm?

By reception count, it's dramatic: ~2% of packet identities generated 69% of everything this logger wrote down. In row-count terms, the legitimate mesh is a minority signal

In [8]:

within its own capture.

But receptions aren't airtime, and airtime is what congests a channel. If we look at the log, the storm packets were 22–26 bytes. Almost the smallest that they can be. A LongFast airtime for a packet that size is a fraction of what a 180-byte text takes. So the storm's share of channel occupancy, which is the thing that actually collides with people's messages, is smaller than its share of the row count. How much smaller is computable! We have size per reception, so airtime-weighting the same cumulative
curve can be done.

sz = q("""SELECT size, COUNT(*) n,
CASE WHEN cnt > 15 THEN 'storm' ELSE 'normal' END cls FROM trace_raw_packe JOIN (SELECT from_node fn, packet_id pid, COUNT(*) cnt
FROM trace_raw_packets GROUP BY 1,2) g
ON g.fn=r.from_node AND g.pid=r.packet_id
GROUP BY size, cls""")
if len(sz):
# LoRa airtime scales ~linearly with payload at fixed preset; bytes×coun sz["bytes"] = sz["size"].fillna(0) * sz.n

share = sz.groupby("cls")["bytes"].sum()
print((share / share.sum()).round(3))

cls
normal | 0.384
storm | 0.616
Name: bytes, dtype: float64
If this comes back with the storm class at, say, 30–40% of byte-share rather than 69% of receptions, the finding means the storm dominated the packet census but contributed a large-minority share of channel load. This is still a major distortion of the environment everyone was debating, but not "the channel was 69% garbage." Whichever number emerges is the one the write-up should lead with, because airtime is the physically meaningful currency.

And again this is only one aperture's view. The 31st floor hears re-injections from every gateway in the valley simultaneously, and a con-floor node inside one gateway's neighborhood is going to only experience some fraction of this and not all of it. Cross-checking the storm share at the a5fe aperture isn't possible (its app-level log deduplicated by packet ID so the storm is invisible there by construction, which is itself a finding about instrument choice), but the megalog and Sahara captures can vote once they open.

We get 61.6% by bytes, 69% by receptions. This is nearly the same number. Airtime-weighting barely moved it, and in hindsight the reason is kind of obvious in the data we already had. The normal class isn't long messages either. The normal class is dominated by NODEINFO/POSITION/TELEMETRY beacons, themselves small packets. Small-versus-small, so the weighting couldn't dilute the storm's share. It's a good thing to check and apply in other situations, but doesn't do much here.

In [9]:

Per byte delivered, the storm burned more airtime than normal traffic, not less. So 62% is the storm's floor as a share of channel occupancy at this aperture. The preamble-corrected figure would be higher.

Which means the "is this a bad storm" question is settled (with caveats of course). At the FB31 aperture, the majority of channel load during DEF CON 34 was pathological traffic. It looks like re-originated small packets consistent with retry/gateway-re-injection storms. Every utilization number anyone quoted from experience that weekend ("75% and worked fine," "congestion was bad on ShortTurbo") was measured against a channel that was more than half echo. We are comparing two presets' performance during an unrecognized, distributed, multi-day flood event.

# Canonical storm derivation — all later cells reuse these sets.

# Storm nodes: identities whose packets were re-originated (heard direct-fro # origin, full budget: hop_start == hops_away) more than THRESH times. Deriv # from the source DB at runtime — nothing hardcoded — and raw IDs never prin # each node gets a stable rank label S1..Sn ordered by reception volume. STORM_REORIG_THRESH = 10

storms = q(f"""SELECT from_node, COUNT(DISTINCT packet_id) storm_packets, SU datetime(MIN(t),'unixepoch') first_seen, datetime(MAX(t),'unixepoch') last_s (SELECT from_node, packet_id, COUNT(*) cnt, MIN(trace_timestamp) t FROM trac WHERE hop_start = hops_away AND hop_start > 0 AND trace_timestamp > 1e9 GROUP BY 1,2 HAVING cnt > {STORM_REORIG_THRESH})
GROUP BY 1 ORDER BY receptions DESC""")

# now derive the rank mapping FROM the query result (order matters): storm_rank = {int(n): f"S{i+1}" for i, n in enumerate(storms.from_node)} STORM_NODES = set(storm_rank)

# storm PACKET ids too (harmless serials, derived for consistency):

_sp = q("""SELECT from_node, packet_id, COUNT(*) c FROM trace_raw_packets GROUP BY 1,2 HAVING c > 15 ORDER BY c DESC LIMIT 10""")
STORM_IDS = set(int(p) for p in _sp.packet_id)

print(f"derived {len(STORM_NODES)} storm nodes (S1..S{len(STORM_NODES)}), " f"{len(STORM_IDS)} top storm packet-ids")

# the table, rank-labelled (raw from_node never shown):

top10 = storms.head(10).copy()
top10.insert(0, "node", top10.from_node.map(storm_rank)) print(top10.drop(columns=["from_node"]).to_string(index=False))

In [10]:

derived 570 storm nodes (S1..S570), 10 top storm packet-ids
node storm_packets receptions | first_seen | last_seen
S1 | 398 | 23986 2026-08-04 14:03:01 2026-08-09 07:28:55
S2 | 164 | 18743 2026-08-05 20:41:09 2026-08-09 17:23:53
S3 | 19 | 11290 2026-08-07 02:19:55 2026-08-08 17:45:22
S4 | 28 | 11073 2026-08-06 01:56:40 2026-08-08 21:43:01
S5 | 19 | 10309 2026-08-07 20:34:43 2026-08-08 08:47:35
S6 | 24 | 10135 2026-08-06 01:37:59 2026-08-09 00:57:15
S7 | 90 | 9728 2026-08-06 04:33:05 2026-08-06 16:48:51
S8 | 72 | 9614 2026-08-08 07:35:37 2026-08-09 15:57:31
S9 | 78 | 8176 2026-08-06 01:34:10 2026-08-08 23:40:17
S10 | 34 | 7316 2026-08-06 01:07:55 2026-08-07 01:28:08

# Portrait of one storm: hourly copies of the top packet (id resolved locall top = q("""SELECT from_node, packet_id FROM trace_raw_packets

GROUP BY 1,2 ORDER BY COUNT(*) DESC LIMIT 1""")
if len(top):
fn, pid = int(top.from_node[0]), int(top.packet_id[0])
tl = q(f"""SELECT strftime('%m-%d %Hh', trace_timestamp,'unixepoch') h, FROM trace_raw_packets WHERE from_node={fn} AND packet_id={pid} AND trac GROUP BY h ORDER BY h""")
tl.plot(x="h", y="n", kind="bar", legend=False, color="#7a3b46") plt.title("FB31: hourly copies of the single most-duplicated packet (UTC plt.xlabel(""); plt.tight_layout()

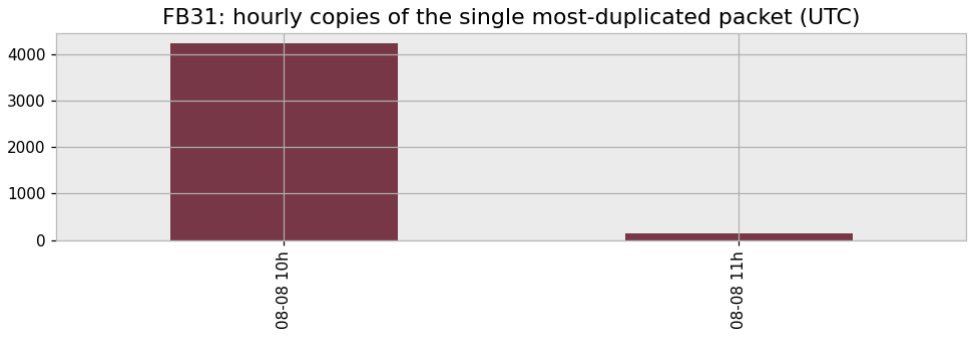
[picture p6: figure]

## 2.2 Clocks: machine tide vs human day

De-storming the hourly histogram tells us whether the striking ~3-hour periodicity belongs to the pathological class (spoiler: it does, mostly). Decoded TEXT traffic supplies the human clock. The overnight trough double-confirms the timezone (UTC timestamps and Vegas = UTC−7).

hr_all = q("""SELECT strftime('%H', trace_timestamp,'unixepoch') hr, COUNT(* FROM trace_raw_packets WHERE trace_timestamp > 1e9 GROUP BY hr ORDER BY hr"" hr_ds = q(f"""WITH storms AS (SELECT from_node, packet_id FROM trace_raw_pac GROUP BY 1,2 HAVING COUNT(*) > {STORM_THRESHOLD})
SELECT strftime('%H', trace_timestamp,'unixepoch') hr, COUNT(*) n FROM trace WHERE trace_timestamp > 1e9 AND NOT EXISTS
(SELECT 1 FROM storms s WHERE s.from_node=r.from_node AND s.packet_id=r.pac GROUP BY hr ORDER BY hr""")

hr_txt = q("""SELECT strftime('%H', trace_timestamp,'unixepoch') hr, COUNT(* In [11]: In [12]:

FROM trace_decoded_packets WHERE resolved_portnum_name='TEXT_MESSAGE_APP' AND trace_timestamp > 1e9 GROUP BY hr ORDER BY hr""")
if len(hr_all):
fig, ax = plt.subplots(1, 3, figsize=(13, 3))
for A, df, t in [(ax[0], hr_all, "all receptions"), (ax[1], hr_ds, "de-s (ax[2], hr_txt, "decoded TEXT (human clock)")]: A.bar(df.hr, df.n, color="#7a3b46"); A.set_title(f"FB31 hourly (UTC) A.set_xticks(range(0, 24, 3)); A.set_xticklabels([f"{h:02d}" for h i plt.tight_layout()
if len(hr_txt):
trough = hr_txt.sort_values("n").head(4).hr.tolist()
print(f"TEXT trough at UTC hours {sorted(trough)} ends up being ~2–5

TEXT trough at UTC hours ['09', '10', '11', '12'] ends up being ~2–5 AM Paci fic: timestamps are UTC

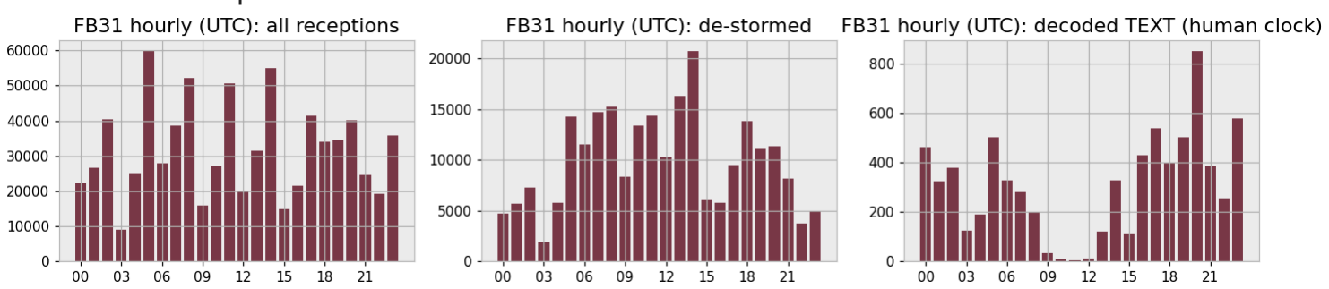
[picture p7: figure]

# 3 Findings (measured, this-archive-only) & consequences for Sending Stones

1. Census brackets the legend: 2,123 (a5fe) and 2,782 (FB31) unique senders compares close to the claimed 2,500+.
2. The channel talks mostly to itself: ~75% of a5fe traffic is protocol housekeeping, not text.
3. A majority of receptions at FB31 belong to a pathological class: >15-copy packets carry ~61% of all receptions. Top offenders show the full-budget re-origination signature over multi-day spans, consistent with retry storms and/or MQTT gateway re-injection loops. The DC34 preset debate compared two presets' handling of a load that was substantially not user traffic! And, no participant could see that without a duplicates-preserving capture.
4. Field semantics are collector-specific: | hops_away | here = budget remaining;
hop_start = 0 | means unknown. Both are now parser doctrine stuff for Sending
Stones' | collate.py | .
5. Timestamps are UTC, we can see the human sleep cycle in TEXT traffic. The largest single storm ran ~3 AM Vegas time on Saturday.
6. Design consequences: probes stay trivially separable from pathology (broadcast, want_ack=0, fixed hop limit, published schedule). The analysis plan gains an ambient-classification stage (organic vs storm) before any utilization curve. And, probe packet-count share needs a peak-hour calibration check against these captures.

What no query here can produce: a delivery ratio. That requires a known denominator, which requires controlled offered load, which is the Sending Stones experiment.

# 4 The storm hunt, in the order it happened

Everything above was measured at single apertures. What follows is the cross-instrument hunt for the storm's mechanism, preserved in discovery order, including two hypotheses that the data proposed, tested, and killed. The dead ends are kept deliberately. Each one was eliminated by an instrument that could falsify it, which is the resource the original DC34 preset debate lacked.

Hypothesis 1 (immortal packets): TTL-stripped packets circulating for days (a known DEF CON prank! See the DC33 spoofing incident). Killed in §2.1 by a single timestamp query. The top storm packet's 5,672 copies landed almost entirely in one hour (3 AM Vegas time, Saturday). Bursts, not ghosts.

Hypothesis 2 (retry storm / MQTT gateway re-injection): the full-budget signature ( hop_start == hops_away ) showed origins re-transmitting at machine rate with escalating hop limits (4 to 5 to 6 to 7 on one packet id) which is behavior consistent with either broken/hostile firmware on the air, or multiple MQTT gateways re-injecting broker traffic back into RF. The next sections test that fork against every other resource in the archive.

## 4.1 The megalog opens: five artifacts, one family tree

The 2.8 GB | DEFCON34-deduplicated-megalog.db | turned out not to be an
independent capture but a merge of everything else in the archive and a carefully
engineered one. Its | merge_sources | table is really good provenance. Feeb's
megalogger is 814,441 rows, the broker-side malla/postgres exports, the a5fe app CSV (39,837 rows, which was row-for-row our copy), and 49 Sahara SDR log files.
The dedup design matches contest-log discipline: | merge_observations | keeps every
observation with a | disposition | (the practice log, dupes retained and adjudicated).
mega_canonical_records | holds one row per | semantic_key | (the turn-in log). Per-
source | time_basis | and | packet_id_basis | columns record that different
instruments had different clock and identity semantics. The merger did not silently normalize.

Two consequences: the megalog's trace layer is not independent corroboration of the FB31 storm (it is mostly Feeb's data), but the broker-side sources inside it enable a
decisive test of the MQTT hypothesis. (Note: | source_path | values in this database
embed the merger's local username so never render that column in exported output.)

MEGA_DB = "DEFCON34-deduplicated-megalog.db" import os
HAVE_MEGA = os.path.exists(MEGA_DB)

def qm(sql):
if not HAVE_MEGA:
print("megalog not present; skipping"); return pd.DataFrame() with sqlite3.connect(MEGA_DB) as cx:
return pd.read_sql_query(sql, cx)

print(qm("""SELECT source_kind, COUNT(*) sources, SUM(expected_rows) rows FROM merge_sources GROUP BY 1 ORDER BY rows DESC""").to_string(index=False)) print()
print(qm("SELECT disposition, COUNT(*) n FROM merge_observations GROUP BY 1"
source_kind sources | rows
feeb_megalogger_v2 | | 1 814441
sahara_sdr_log | | 49 619773
mqtt_unfiltered_sqlite | | 1 59194
postgres_packet_export_csv | | 1 58323
meshtastic_app_datalog_csv | | 1 39837
mqtt_public_sqlite | | 1 12132
disposition | n
anchor 188955
exact_duplicate 464
semantic_duplicate 712635
standalone 701646

## 4.2 The decisive test: did the storm touch the broker?

If MQTT gateway re-injection powered the storm, the broker's own ledger should be full of the storm packet ids cycling through. The megalog contains that ledger
( mqtt_unfiltered_sqlite | , | mqtt_public_sqlite | ,
postgres_packet_export_csv | ), so the hypothesis meets the one instrument that
would know.

t = qm(f"""SELECT mo.packet_id_value pid, ms.source_kind, COUNT(*) n FROM merge_observations mo JOIN merge_sources ms USING(source_id) WHERE mo.packet_id_value IN ({','.join(str(i) for i in STORM_IDS)}) GROUP BY 1,2 ORDER BY 1, n DESC""")

if len(t):
pid_rank = {p: f"P{i+1}" for i, p in enumerate(sorted(STORM_IDS))} t["pid"] = t["pid"].map(lambda x: pid_rank.get(int(x), "other")) print(t.to_string(index=False))

# In [13]: In [14]:

pid | source_kind | n
P1 | feeb_megalogger_v2 2789
P1 postgres_packet_export_csv | 1
P1 | mqtt_unfiltered_sqlite | 1
P1 | mqtt_public_sqlite | 1
P2 | feeb_megalogger_v2 5674
P3 | feeb_megalogger_v2 2364
P3 | mqtt_unfiltered_sqlite | 2
P3 | mqtt_public_sqlite | 2
P3 postgres_packet_export_csv | 1
P4 | feeb_megalogger_v2 4075
P5 | feeb_megalogger_v2 2643
P6 | feeb_megalogger_v2 3206
P6 postgres_packet_export_csv | 1
P6 | mqtt_unfiltered_sqlite | 1
P6 | mqtt_public_sqlite | 1
P7 | feeb_megalogger_v2 4525
P8 | feeb_megalogger_v2 3651
P9 | feeb_megalogger_v2 2835
P9 postgres_packet_export_csv | 1
P9 | mqtt_unfiltered_sqlite | 1
P9 | mqtt_public_sqlite | 1
P10 | feeb_megalogger_v2 2887
P10 postgres_packet_export_csv | 1
P10 | mqtt_unfiltered_sqlite | 1
P10 | mqtt_public_sqlite | 1
Verdict: hypothesis 2 (MQTT echo) is disconfirmed! Every storm packet appears in the broker-side sources at most once; the largest storm (5,674 copies at FB31) never touched the broker at all. The server barely met these packets. Surviving reading: RF-side re-origination which is devices themselves transmitting at machine rate. (Caveat: if the broker collectors dedup by packet id on ingest, a loop would also show once but I do not think that total absence of the top storm cannot be explained that way.)

That leaves one cross-check: did any other RF aperture hear the storm? The merge's own matching cannot answer this. Sahara rows carry no packet ids and no absolute time,
and the | defcon34-conservative-v1 | profile matched zero semantic keys between
Feeb and Sahara across 1.6 M observations. A null from a matcher that couldn't match is not evidence, and can't prove what we're after. The raw Sahara files, however, don't need the merge to filter.

## 4.3 Aperture C: the Sahara SDR capture has PHY layer, headers in the clear

The Sahara files are raw demodulator output ( lorarx ): parallel SF7–SF11 decoders on 500 kHz windows at 906.875 MHz (LongFast slot) and 917.25 MHz, one JSON frame per decode with measured airtime ( duration , ms), SNR, level, noise floor, CRC status, and the raw LoRa frame as base64. This is the instrument class DESIGN.md Appendix A said nobody would run. Someone ran it! This is really good.

LoRa payload encryption starts after the radio header, so bytes 0–11 (dest, sender, packet id, all little-endian) are readable on every frame regardless of channel keys. The storm test can therefore run at the PHY layer, bypassing the merge entirely. The window is wide open ( id=Off , no sync-word filter): it caught all LoRa in the band, so frames must be classified (CRC-valid + plausible header) rather than trusted.

import base64, glob, json, struct
import pandas as pd

rows = []
for path in sorted(glob.glob("sahara/*.txt")):
fname = path.split("/")[-1]
tool, d, t, freq = fname.replace(".txt","").split("-")
for line in open(path, errors="ignore"):
if not line.startswith('{"'): continue | # skip decoder heade
try: j = json.loads(line)
except json.JSONDecodeError: continue
try: raw = base64.b64decode(j.get("payload",""))
except Exception: raw = b""
dest = frm = pid = None
if len(raw) >= 12:
dest, frm, pid = struct.unpack("<III", raw[:12]) rows.append(dict(file=fname, tool=tool, freq_khz=int(freq), sf=j.get("sf"), bw=j.get("bw"), crc=j.get("crc"), dur_ms=j.get("duration"), snr=j.get("snr"), level=j.get("level"), nbytes=len(raw), dest=dest, frm=frm, pid=pid))
s = pd.DataFrame(rows)
print(f"frames: {len(s)} | files: {s.file.nunique()} | freqs: {sorted(s.freq
print(f"CRC field values: {s.crc.value_counts().to_dict()}") print(f"broadcast-dest frames (0xFFFFFFFF): {(s.dest==0xFFFFFFFF).sum()}")

# THE storm test — at the PHY layer, no merge required

hits = s[s.pid.isin(STORM_IDS)]
print(f"\nstorm-ID frames heard at Aperture C: {len(hits)}")
if len(hits):
pid_rank = {p: f"P{i+1}" for i, p in enumerate(sorted(STORM_IDS))} print(hits.pid.map(lambda x: pid_rank.get(int(x), "other")).value_counts .rename_axis("packet").to_string())
frames: 574208 | files: 42 | freqs: [906875, 917250]
CRC field values: {0: 310367, -1: 184965, 1: 78876}
broadcast-dest frames (0xFFFFFFFF): 72359

storm-ID frames heard at Aperture C: 6
packet
P3 6
Result: reach proven, rage absent, and a new question. Six frames, one storm id. Storm traffic could cross the Strip and this instrument could hear it, but the specific bursts didn't rage here. These files are heavily Sunday; the monster bursts were Thursday–Saturday. The sharper question is not "did Sahara hear those ten packets"

In [15]:

(time-bound bursts) but "did Sahara hear the storm nodes" — several of which were still storming into Sunday according to the FB31 table.

The occupancy summary below is the other PHY dividend: summed measured airtime per file. (Interpretation pending two denominators. The true file spans from filename gaps, and cross-SF dedup. This is the same RF burst can decode at two SFs. CRC-valid filtering gives the honest floor.)

occ = (s.groupby(["freq_khz","file"])["dur_ms"].sum() / 1000).groupby("freq_
print(occ) | # seconds of airtime per file, by frequency window
count | mean | std | min | 25% | 50% \
freq_khz
906875 | 14.0 982.155929 860.796598 17.363 | 35.93525 1522.6475
917250 | 28.0 817.079286 327.067825 | 7.332 846.23550 | 907.3260
75% | max
freq_khz
906875 1747.5315 1775.052
917250 1038.2845 1137.507

## 4.4 From packets to perpetrators: the storm-node census at the Sahara

# STORM NODES is our new band name

# Bit layout per Meshtastic header as of firmware 2.7.x

# validated empirically by the structured hop-field distribution (§4.5).

# If the table ever comes out deranged, suspect the bit-unpacking before the

sn = s[s.frm.isin(STORM_NODES)]
print(f"frames from storm NODES at Aperture C: {len(sn)}")
if len(sn):
print(sn.frm.map(storm_rank).value_counts().rename_axis("node").to_strin

# In [16]: In [17]:

frames from storm NODES at Aperture C: 113520 node
S218 | 28223
S2 | 8725
S49 | 8457
S14 | 6692
S8 | 6376
S390 | 5059
S19 | 4046
S129 | 2972
S82 | 2578
S1 | 2534
S144 | 2075
S69 | 2012
S56 | 1890
S383 | 1825
S111 | 1686
S42 | 1684
S378 | 1481
S300 | 1438
S13 | 1406
S12 | 1352
S343 | 1282
S21 | 1205
S187 | 1200
S183 | 1117
S272 | 924
S248 | 866
S492 | 792
S60 | 741
S18 | 650
S265 | 625
S40 | 618
S73 | 514
S87 | 492
S298 | 468
S570 | 466
S15 | 458
S204 | 452
S161 | 398
S48 | 368
S64 | 343
S117 | 310
S289 | 300
S244 | 289
S29 | 256
S295 | 231
S210 | 228
S122 | 221
S338 | 215
S519 | 202
S128 | 199
S280 | 193
S109 | 191
S495 | 191
S214 | 178

S53 | 160
S359 | 150
S377 | 147
S133 | 128
S61 | 123
S475 | 113
S349 | 113
S440 | 100
S37 | 99
S101 | 95
S536 | 91
S323 | 91
S233 | 84
S17 | 80
S274 | 79
S340 | 77
S421 | 73
S267 | 64
S411 | 62
S423 | 58
S345 | 55
S240 | 54
S44 | 51
S532 | 50
S23 | 49
S254 | 47
S242 | 44
S148 | 40
S264 | 37
S310 | 35
S294 | 34
S163 | 32
S34 | 32
S89 | 32
S487 | 31
S402 | 27
S277 | 26
S307 | 26
S391 | 26
S540 | 25
S569 | 25
S196 | 25
S241 | 25
S27 | 25
S50 | 24
S105 | 22
S77 | 22
S249 | 21
S312 | 20
S217 | 18
S535 | 18
S6 | 17
S469 | 17
S537 | 16
S110 | 16
S104 | 15

S478 | 15
S25 | 14
S63 | 14
S94 | 14
S321 | 14
S225 | 13
S85 | 13
S296 | 12
S108 | 12
S370 | 12
S256 | 12
S446 | 12
S505 | 11
S4 | 11
S126 | 11
S399 | 11
S302 | 10
S195 | 10
S533 | 10
S447 | 10
S512 | 9
S287 | 9
S22 | 9
S496 | 9
S54 | 9
S381 | 9
S448 | 8
S544 | 8
S325 | 8
S47 | 8
S481 | 8
S444 | 7
S5 | 7
S157 | 7
S563 | 7
S81 | 7
S247 | 7
S376 | 6
S57 | 6
S97 | 6
S123 | 6
S330 | 6
S494 | 6
S211 | 6
S158 | 6
S515 | 6
S270 | 6
S443 | 6
S308 | 6
S337 | 5
S328 | 5
S165 | 5
S491 | 5
S315 | 5
S213 | 5
S358 | 5

S506 | 5
S154 | 5
S80 | 5
S367 | 5
S132 | 5
S159 | 5
S151 | 5
S385 | 5
S189 | 5
S190 | 5
S260 | 5
S435 | 5
S168 | 5
S366 | 5
S463 | 5
S285 | 4
S348 | 4
S96 | 4
S251 | 4
S415 | 4
S365 | 4
S153 | 4
S46 | 4
S324 | 4
S547 | 4
S408 | 4
S445 | 4
S33 | 4
S219 | 4
S397 | 4
S250 | 4
S405 | 4
S152 | 4
S38 | 4
S115 | 4
S545 | 3
S224 | 3
S198 | 3
S305 | 3
S259 | 3
S364 | 3
S313 | 3
S460 | 3
S354 | 3
S514 | 3
S382 | 3
S394 | 3
S292 | 3
S426 | 3
S143 | 3
S306 | 3
S400 | 3
S41 | 3
S179 | 2
S441 | 2
S185 | 2

S396 | 2
S188 | 2
S30 | 2
S357 | 2
S363 | 2
S135 | 2
S318 | 2
S91 | 2
S71 | 2
S489 | 2
S139 | 2
S543 | 2
S480 | 2
S565 | 2
S431 | 2
S549 | 2
S417 | 1
S70 | 1
S220 | 1
S45 | 1
S327 | 1
S83 | 1
S416 | 1
S553 | 1
S470 | 1
S231 | 1
S52 | 1
S468 | 1
S459 | 1
S199 | 1
S184 | 1
S175 | 1
S113 | 1
S186 | 1
S171 | 1
S509 | 1
S356 | 1
S479 | 1
S539 | 1
S43 | 1
S520 | 1
S194 | 1
S206 | 1
S522 | 1
S174 | 1
17,670 frames from storm nodes is 3% of everything the Sahara heard and the top three match FB31's ranking. The persistent stormers (multi-day spans in the FB31 table) were audible miles away and still transmitting on the con's last day. The bursty nodes show only trace counts, exactly what Sunday-only coverage of Thursday through Saturday bursts predicts.

First half of the final verdict: the storm was node-specific (a handful of identifiable devices, not an emergent mesh property) but RF-wide (independent apertures, miles apart). One question remains: at the Sahara, were these frames heard from the origins (full budget, like FB31) or as flood relays? The hop fields in header byte 12 answer that.

## 4.5 The hop-field table: reading byte 12

Header byte 12 packs | hop_limit | (bits 0–2, budget remaining), | want_ack | (bit 3),
via_mqtt | (bit 4 is gateway-injected frames self-identify), | hop_start | (bits 5–7,
budget at launch); byte 13 is the channel hash. Restricted to CRC-valid frames so header bytes are trustworthy. The grid below is hop_start (rows) * hop_limit (columns): the diagonal is full-budget = heard direct from origin FB31's signature. Mass below the diagonal = relayed copies. Whew!

import base64, glob, json, struct
import pandas as pd

rows = []
for path in sorted(glob.glob("sahara/*.txt")):
fname = path.split("/")[-1]
tool, d, t, freq = fname.replace(".txt","").split("-") for line in open(path, errors="ignore"):
if not line.startswith('{"'): continue
try: j = json.loads(line)
except json.JSONDecodeError: continue
try: raw = base64.b64decode(j.get("payload","")) except Exception: continue
if len(raw) < 14: continue
dest, frm, pid = struct.unpack("<III", raw[:12])
flags = raw[12]
rows.append(dict(file=fname, freq_khz=int(freq), crc=j.get("crc"), dur_ms=j.get("duration"), snr=j.get("snr"), dest=dest, frm=frm, pid=pid,
hop_limit=flags & 0x07, | # bits 0-2: budget
want_ack=(flags >> 3) & 1, | # bit 3
via_mqtt=(flags >> 4) & 1, | # bit 4: gateway-i
hop_start=(flags >> 5) & 0x07, | # bits 5-7: origin
chan_hash=raw[13]))
sf = pd.DataFrame(rows)
print(f"parsed {len(sf)} frames with headers")

parsed 549419 frames with headers

ok = sf[(sf.crc == 0) & (sf.frm.isin(STORM_NODES))]
print(f"CRC-valid storm-node frames: {len(ok)}")

# THE table: hop_start vs hop_limit (diagonal = full budget = heard direct-f tab = ok.groupby(["hop_start","hop_limit"]).size().unstack(fill_value=0) print(tab)

diag = (ok.hop_start == ok.hop_limit).mean()
print(f"\nfull-budget share (hop_start == hop_limit): {diag:.0%}") print(f"want_ack share: {ok.want_ack.mean():.0%}") print(f"via_mqtt share: {ok.via_mqtt.mean():.0%}")

# In [18]: In [19]:

print(f"\nchannel hashes: {ok.chan_hash.value_counts().head(5).to_dict()}") print("(Feeb's decoded-primary hash was 209 — match = same channel)")

CRC-valid storm-node frames: 44458
hop_limit | 0 | 1 | 2 | 3 | 4 | 5 | 6 | 7
hop_start
0 | 294 | 90 | 45 | 18 | 37 | 19 | 22 | 7
1 | 352 | 83 | 49 | 18 | 46 | 29 | 18 | 4
2 | 317 | 85 | 45 | 45 | 46 | 18 | 26 | 9
3 | 15258 2993 757 173 214 115 | 65 15
4 11173 2084 535 167 351 304 116 37
5 | 2804 | 531 178 | 85 107 | 42 | 55 11
6 | 1867 | 397 134 | 53 | 90 | 64 | 39 18
7 | 1313 | 249 105 | 39 | 75 | 45 | 58 20

full-budget share (hop_start == hop_limit): 2%
want_ack share: 37%
via_mqtt share: 3%

channel hashes: {213: 13909, 0: 13323, 14: 7219, 27: 2567, 209: 1602} (Feeb's decoded-primary hash was 209 — match = same channel)
The table is FB31's inverse, and the inversion tells us stuff. At the tower, storm mass sat on the diagonal (heard at origin, full budget). At the Sahara, the mass is crushed into
the | hop_limit=0 | column (which should have been named hot_pockets). Packets
launched with budgets 3–7 arriving with nothing left the flood's dying echoes, heard at
the end of their lives. Only 2% diagonal! | via_mqtt = 3% | : the gateway hypothesis is
buried per-frame, at the layer where it couldn't hide anymore from us poking at it. And the heavily-populated hop_start rows 5–7 corroborate FB31's escalating-budget observation independently: stock firmware doesn't launch above 3. These devices were configured to carry.

Channel hashes 14 and 0 dominate and not 209 (FB31's decoded primary), and 14 was the third-largest hash in FB31's raw census. The storm rode a channel neither aperture could decrypt Which is also why the broker barely saw it. It is plausibly no gateway carried that channel. Every instrument's blindness, which we fully expect and know about, now has a better explanation.

## The storm, assembled

Ten node identities generated the storm. They transmitted from within one tower's direct horizon, with elevated hop budgets, predominantly on an undecrypted channel. The mesh's flood routing amplified them into the majority of measured channel load at that tower and carried their exhausted echoes across the Strip. The MQTT infrastructure, blind to their channel, recorded almost nothing. Every ordinary logging method at the con deduplicated them into invisibility. Two unusual instruments, built independently and joined eleven days later, were required to see it at all. But, we can.

# 5 What this means for Sending Stones (and DC35)

1. The DC34 preset debate compared two presets' handling of a load that was substantially not user traffic. At the FB31 aperture >=62% of channel bytes (a floor, and per-packet preamble overhead raises it) belonged to the pathological class. Neither side of the argument could see it. App-level logging deduplicates the evidence out of existence.
2. Instrument choice determined which network you thought you were on. The most common Meshtastic logging method is structurally blind to the dominant traffic class of DC34.
3. Ambient contamination is now a measured threat model, not a caution. Sending Stones' design responses want_ack=0 broadcast probes, fixed stock hop limits, published schedule, and a storm-classification stage before any utilization curve and are calibrated to what these captures measured.
4. No capture here contains a delivery ratio, and none can. No offered load was controlled so no denominator exists. Characterizing what was heard is the ceiling of retrospective analysis. Measuring what is delivered requires an experiment such as github.com/OpenResearchInstitute/sending-stones.

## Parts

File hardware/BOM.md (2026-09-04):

# Sending Stones Bill of Materials (Rev B.1)

Six identical station kits (5 deploy + 1 Stone of Reserve) + bench devices.
Philosophy: one SKU per role, one lot where possible, boring known-good parts.
The station host is a **Raspberry Pi 4**. See DESIGN.md §4.1 for why (and for
the roads not taken: USB hub + Pi Zero, GPIO UARTs, WiFi/TCP, ESP32 host,
custom radio firmware).

## Radios
| Qty | Item | Source | Notes |
|---|---|---|---|
| 14 | Heltec V3, **US915** | Rokland (single order/lot) or Heltec direct | 12 deploy + 2 bench mules (permanent San Diego pair). Deliberately V3, not V4 so that the station matches deployed population (DESIGN §4). **Verify 915 MHz variant on every unit at intake.** |

## Station hosts
| Qty | Item | Source | Notes |
|---|---|---|---|
| 7 | Raspberry Pi 4 Model B, 2 GB | CanaKit / PiShop / Adafruit | 6 kits + 1 bench. Four native USB-A ports, both radios direct, no hub. Ethernet for NTP/remote at Stone-FB. |
| 7 | Official Pi 4 USB-C PSU, 5.1 V/3 A | same | One SKU x 7. Underpowered adapters cause brownouts that masquerade as software bugs. |
| 6 | **Geekworm X728** + 2× 18650 (2500 mAh class), field-proven ~1 hr on Pi 4 + two USB dongles (WWWD 2022 testing) | Amazon / vendor direct | Target: bridge blips and brief outages (hours, not days). Must pass plug-yank test. I2C battery telemetry written to events table where supported. |
| 8 | High-endurance 32 GB microSD (SanDisk High Endurance / Samsung PRO Endurance) | Amazon / B&H | 6 + 2 spares + imaging reader. Endurance rating matters more than capacity for logging. |

## RF
| Qty | Item | Source | Notes |
|---|---|---|---|
| 14 | **TE/Linx ANT-916-CW-HW-SMA** (Digi-Key `ANT-916-CW-HW-SMA-ND`) | Digi-Key | 12 deploy + 2 spare. half-wave center-fed dipole, 916 MHz center / 30 MHz BW (covers both channels), 1.2 dBi, VSWR 1.9, 50 Ω, SMA **male**, 4.72 in. Half-wave chosen deliberately: no ground-plane dependence, so aperture matching lives in the antenna, not in six subtly different installations. |
| 6 | Spare IPEX→SMA-female bulkhead pigtails (V3 conversion package incl. nut/washer) | Rokland (add to radio order) | U.FL/IPEX is good for ~30 mating cycles, so treat as consumable. Bench rule: seat IPEX **once** at intake, mount SMA bulkhead to enclosure, all subsequent cycles happen at the SMA. |

## Cables & power contingency
| Qty | Item | Notes |
|---|---|---|
| 14 | Short USB-**A**-to-C data cables | V3 has a documented C-to-C charging quirk and having it short is less station spaghetti |
| 1–2 | Pass-through-rated power bank | No outlet available contingency only, still subject to plug-yank test |

## Field kit
Gaffer tape, velcro, zip ties, label maker (label every Stone, radio, SD, PSU 
**cohort A/B mixups are a silent data poisoner**), small ventilated enclosures
(Printables has V3 cases to remix), spare fuses for optimism. Go team optimism!

## Intake checklist (receiving = Phase 0 step 1)
- [x] Every Heltec: confirm US915 silkscreen/label; flash stock firmware; label A/B + Stone ID
- [ ] Every antenna: ANT-916-CW-HW-SMA marking check (NOT the RP-SMA sibling); thread onto an SMA-female pigtail
- [x] Every pigtail: seat IPEX once, mount bulkhead, mark radio as antenna-committed
- [x] Every Pi: boot golden image; both radios enumerate under /dev/serial/by-id/ with stable names
- [ ] Every UPS HAT: plug-yank test under live logging — any reboot = fail/return
- [x] Every PSU: check for undervoltage warnings in dmesg under full station load
- [ ] Bench mules set aside and never packed for Vegas

Estimated total: ~$1500 all-in with bench devices and field kit. Final BOM cost will be here and larger after everything works.

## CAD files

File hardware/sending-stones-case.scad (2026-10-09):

// Sending Stones Model Railroad Layout
// ------------------------------------
// Abraxas3d
// units are in mm


// ------------------------------------
// Parameters
// ------------------------------------

//make curves nice
$fn = 64;

// base layer dimensions
base_width = 700;
base_depth = 200;
base_height = 6.25; // quarter inch acrylic sheet

// X728 box dimensions (approximate)
x728_width = 122;
x728_depth = 92;
x728_height = 60;
    
// Ground plane and donut stand dimensions
ground_plane_radius = 100; //~quarter wave ground plane
ground_plane_height = 1; // 1 mm aluminum plate
donut_height = 2*24.5; //one inch height increments
donut_radius = 24.5; //one inch radius
donut_hole_radius = 8; // 16 mm clearance for SMA bulkhead connector in donut
sma_hole_radius = 6.5/2; // 6.5 mm hole for SMA connector

// Heltec v3 case dimensions
heltec_width = 56;
heltec_depth = 30;
heltec_height = 11;
heltec_wall = 2;
usb_width = 9.5;
usb_height = 4;
usb_sill = 5;

// ------------------------------------
// Components Defined
// ------------------------------------

// the base layer
cube([base_width, base_depth , base_height], center = true);

// X728
translate([0, -base_depth/6, base_height/2 + x728_height/2])
    {
    cube([x728_width, x728_depth, x728_height], center = true);
    };

// Ground plane donut hole mounts with cable cutout
translate([-250, 0, base_height/2 + donut_height/2])
    {
    difference()
        {
        cylinder(donut_height, donut_radius, donut_radius, center = true); //donut
        cylinder(donut_height, donut_hole_radius, donut_hole_radius, center = true); //hole
        translate([donut_radius/2, 0, 0])
            {
            cube([donut_radius, donut_hole_radius*2, donut_height], center = true); //channel out
            };
        };
    };
    
translate([250, 0, base_height/2 + donut_height/2])
    {
    difference()
        {
        cylinder(donut_height, donut_radius, donut_radius, center = true);
        cylinder(donut_height, donut_hole_radius, donut_hole_radius, center = true);
        translate([-donut_radius/2, 0, 0])
            {
            cube([donut_radius, donut_hole_radius*2, donut_height], center = true);
            };
        };
    };

// Ground planes with SMA bulkhead holes
translate([-250, 0, base_height/2 + donut_height + ground_plane_height/2])
    {
   difference()
        {
        cylinder(ground_plane_height, ground_plane_radius, ground_plane_radius, center = true);
        cylinder(ground_plane_height, sma_hole_radius, sma_hole_radius, center = true);
        };
    };
    
translate([250, 0, base_height/2 + donut_height + ground_plane_height/2])
    {
    difference()
        {
        cylinder(ground_plane_height, ground_plane_radius, ground_plane_radius, center = true);
        cylinder(ground_plane_height, sma_hole_radius, sma_hole_radius, center = true);
        }
    };

// Heltec v3 holders

translate([-120, base_depth/4, base_height/2])
    {
    cube([heltec_width, heltec_depth, heltec_wall], center = true); //base
    }


translate([-120, base_depth/4, base_height/2 + heltec_height/2])
    {
    difference()
        {
        cube([heltec_width, heltec_depth, heltec_height], center = true); // case
        cube([heltec_width - 2*heltec_wall, heltec_depth - 2*heltec_wall, heltec_height], center = true); // interior case
        
        //translate([0,0,-(heltec_height/2) + heltec_wall + usb_sill])
        translate([0,0,-(heltec_height/2) + heltec_wall + usb_sill + usb_height/2])
        {
        cube([heltec_width + 4*heltec_wall, usb_width, 2*usb_height], center = true); // holes
        }
        }
    };
 

translate([120, base_depth/4, base_height/2])
    {
    cube([heltec_width, heltec_depth, heltec_wall], center = true); //base
    }


translate([120, base_depth/4, base_height/2 + heltec_height/2])
    {
    difference()
        {
        cube([heltec_width, heltec_depth, heltec_height], center = true); // case
        cube([heltec_width - 2*heltec_wall, heltec_depth - 2*heltec_wall, heltec_height], center = true); // interior case
        
        translate([0,0,-(heltec_height/2) + heltec_wall + usb_sill + usb_height/2])
        {
        cube([heltec_width + 4*heltec_wall, usb_width, 2*usb_height], center = true); // holes
        }
        }
    };

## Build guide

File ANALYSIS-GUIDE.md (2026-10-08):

# How to Analyze the Stations

---

## 0. What do we Have?

Five+ stations (**FB, RFV, HRV, CHILL, SPARE, and COLD on Palmoar**), 
each has a Raspberry Pi 4 with **two** Heltec V3 radios connected.

- **cohort A = LongFast** (BW 250 kHz, SF11)
- **cohort B = ShortTurbo** (BW 500 kHz, SF7)

Every station both **transmits** timed probe packets and **logs** every probe it
hears, into one SQLite DB per station (`mesh_pdr_<NAME>.sqlite`, WAL mode). The
question we're after is packet delivery ratio. 

Specifically, **LongFast vs ShortTurbo packet delivery**, or any A vs. any B 
packet delivery comparison that can be configured on the radios. 

The two presets compute to *different* center frequencies because the channel
slot count depends on the bandwidth (~104 slots at 250 kHz vs ~52 at 500 kHz). 
So cohort A and cohort B in this case are independent and non-interfering 
populations sharing the band.

Measured channel utilization was ~20% on A's frequency and ~0% on B's. 
We can run both at once without them stepping on each other.

---

## 1. How to run the Analysis

- From something like a laptop, in `~/Meshtastic/sending-stones`.
- The Pis are reached over **Tailscale** by ssh aliases: `stone-fb`, `stone-rfv`,
  `stone-hrv`, `stone-chill`, `stone-spare`, `stone-cold`.
- `collate_lab.sh` hardcodes `REMOTE_USER=abraxas3d`. 
- If **nothing** connects then check Tailscale is up (`tailscale status`) before
  blaming the stations.

---

## 2. Everything Still Running?

Before any matrix, confirm all five loggers are up and actually logging. The
one-command check is the health tool:

```bash
./fleet-health.sh
```

Healthy fleet = every row **LOGGER active, WATCHDOG active, CLOCK sync**, and a
small **DB_AGE** (seconds since that stone last wrote its database). Anything
flagged — `*inactive` logger, `NOSYNC` clock, `DB_AGE` with `(!)`, or
`UNREACHABLE` — is the stone to look at.

To dig into one stone:

```bash
ssh abraxas3d@stone-<name>.local 'systemctl status sending-stones --no-pager'
ssh abraxas3d@stone-<name>.local 'journalctl -u sending-stones -f'   # watch it live
```

- **Logger not `active`?** Start it: `sudo systemctl start sending-stones`
  (Section 6). Do NOT launch it by hand with `nohup` — it's a systemd service
  now, and a hand-started copy would fight the service over the serial port.
- **DB_AGE large / `(!)`** (service claims active but isn't writing)? The radios
  may be deaf — wrong region or wrong preset. See Section 5.
- **`UNREACHABLE`?** The stone is off the network (or a slow name path). It keeps
  logging to its local SD regardless; reach it over `.local` or reconnect it.

> The logger is a **systemd service** (`sending-stones`) — it auto-starts on boot
> and auto-restarts on crash. That's the fix for the thing that bit us hard: the
> old hand-started `nohup` logger silently died on a reboot and nobody noticed for
> ~22 hours. **Manage it with `systemctl start/stop`, never `pkill`** — systemd
> respawns a killed process in 5 seconds.

---

## 3. Run the Collation (like collating papers)

```bash
./collate_lab.sh 600        # 600-second (10-minute) window
```

This pulls only the window's probe rows from each station (not the whole DB!) and
prints two delivery matrices, cohort A and cohort B.

A freshly restarted station needs to sit inside a common time window with the others 
before its row means anything. Otherwise its denominator is tiny and the numbers 
look scary for no reason (see Section 4, small-denominator trap). Just wait the 10
minutes and it will be good. 

---

## 4. Enter the Matrix (the whole point of the experiment)

Each cell = **fraction of that sender's probes that that receiver actually logged**,
`|sent ∩ received| / |sent|`, in this window
Rows = sender, columns = receiver.
`--` is self, `.` means the sender sent nothing. The `sent` column is the
**denominator**, which is how many probes that sender put on the air.

**What it should look like on the bench:** ~**1.00** almost everywhere, in
*both* cohorts, as **one coherent block** per cohort.

**The small-denominator trap.** Read the `sent` column *before* reacting to a
low cell. If a station sent only 4 probes, one miss is 0.75 and that is a
quantization, not a bad link. Low cells on a station with a small `sent` count,
especially one just restarted, are almost always quantization artifacts.
Re-run after it has a full window before believing them or getting stressed.

**A genuinely bad link** is a cell that stays low *with a full denominator*,
in a *stable* window, on a *specific* pair. That's when you go chase one radio
and not before.

---

## 5. Failures and Stuff

| Symptom in the data | Cause | Fix |
|---|---|---|
| A station hears **nothing** from anyone (its receive column all `.`/0), logger running | `lora.region` was **UNSET (0)** on that Pi's radios, and therefore radio is deaf/mute | `meshtastic --set lora.region US` on each of its radios (`--port /dev/ttyUSB0` and `/dev/ttyUSB1`) |
| Cohort **B splits into two islands** (two ~1.00 groups, ~0 between) | Some B-radios still on **LongFast** (250/SF11) instead of **ShortTurbo** | `meshtastic --set lora.modem_preset SHORT_TURBO` on the offending B radio (usually `/dev/ttyUSB1`) then verify |
| Delivery cell **> 1.00** (impossible!) | Old bug: count/count division across mis-aligned pull windows | Already fixed, but the join is now probe-level set-intersection. Should not see this again. |
| A station has **two radios but only one cohort logs** | Both radios grabbed the same cohort, or a serial path collided | Check `config.yaml` cohort serials use **`/dev/serial/by-path/`**, not `by-id` (all CP2102 chips report serial `0001`, so `by-id` is ambiguous — `by-path` is stable per physical USB port) |
| Two stations' probes **overwrite each other** which makes a station's numbers look duplicated | Two stations share the same `slot` | `slot` must be **unique per station**: FB=0, RFV=1, HRV=2, CHILL=3, COLD=4, SPARE=5 |
| Everything looks connected but no probes flow | USB cable seated but radio not actually enumerated | A USB cable is power **and** data so reseat, re-check `/dev/serial/by-path/`. |

---

## 6. Operating the fleet safely

Each Stone runs `station.py` as a **systemd service** called `sending-stones`.
It starts automatically on boot and restarts within 5 seconds if it ever exits,
so a reboot or a crash no longer silently stops data collection. It has **no
network dependency** on purpose. A Stone keeps logging to its local SD card
even when it is off the network.

### Day-to-day control

systemd owns the logger now so **do not `pkill` station.py**, or it will respawn
in 5 seconds. Use systemctl:

| Task | Command |
|---|---|
| Stop the logger (e.g. to free the serial ports for `meshtastic` config) | `sudo systemctl stop sending-stones` |
| Start it again | `sudo systemctl start sending-stones` |
| Is it running? | `systemctl is-active sending-stones` |
| Full status | `systemctl status sending-stones` |
| Watch it live! | `journalctl -u sending-stones -f` |

A manual `stop` does work. `Restart=always` only respawns on an *unexpected*
exit, not when you deliberately stop it. It will still auto-start on the next
reboot. For longer maintenance or when you don't want that, also
`sudo systemctl disable sending-stones` (and `enable` when done).

Install (or re-install) the service:

```bash
sudo ./install-resilience.sh
```

`station.py` is restart-safe: it resumes each cohort's seq counter from the DB,
so a restart doesn't reset the experiment. Hard won!

**The golden deletion rule.** While `station.py` is running, a station's live
`mesh_pdr_<THIS>.sqlite` and its `-wal` / `-shm` are **off-limits**. Deleting a
live WAL out from under the writer loses in-flight data. Learned the hard way!

**Don't checkpoint or open a DB with a glob.** `sqlite3 ~/mesh_pdr_*.sqlite "..."`
opens the *wrong* file on a multi-match and fails silently. Always name the one
file. Leanred the hard way!

---

## 7. Shutting Everything Down Safely

`for s in stone-fb stone-rfv stone-hrv stone-chill stone-spare; do
  echo "== $s =="; ssh abraxas3d@$s 'sudo shutdown -h now'
done`

---

## 8. Glossary

- **PDR** — Packet Delivery Ratio: of the probes a sender put on the air, the
  fraction a given receiver logged.
- **cohort A / cohort B** — the two radios per station; A runs LongFast, B runs
  ShortTurbo. Different presets have different center frequencies so they're independent.
- **probe** — a timed packet, payload `PDR|<cohort>|<station>|<seq>|<epoch>|<N|C>`.
  The transmit intent is logged **before** the send, so a failed send is *data*
  (a recorded denominator with an error status), not a missing row.
- **the join key** — `(probe_station, cohort, probe_seq)`. Don't use `probe_seq`
  alone because cohorts A and B share the same seq number space, so seq-only would
  cross-match A's probe #7 with B's probe #7. This is the single most important
  correctness invariant in the whole analysis. Learned the hard way.
- **denominator = intent, not success** — the `sent` count comes from the
  sender's `tx_log` where `api_status='ok'`; the numerator comes from the
  receiver's `rx_log` where `is_probe=1`.

---

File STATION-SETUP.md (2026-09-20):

# Sending Stones Station Setup Guide

Complete procedure to turn a blank Raspberry Pi OS card into a deployed,
remotely-reachable Sending Stones monitoring/PDR station. Follow top to bottom
per station. Steps that have to happen while physically on-site are marked
**[ON-SITE]** and like everything else can be done later over Tailscale.

Tested on: Raspberry Pi 4 (2GB) + Geekworm X728 UPS + Heltec V3 (US915),
Raspberry Pi OS Lite (64-bit), meshtastic-python 2.7.11, firmware 2.7.26.

---

## 0. Before you start

You need:
- Pi 4 imaged with Raspberry Pi OS Lite. During imaging (Raspberry Pi Imager
  gear/customize) set: hostname, enable SSH, your **home** WiFi + a known
  user/password. Turn on "verify after write". Eject cleanly.
- The X728 stack assembled (Pi and standoffs  X728  C1 case), or a bench Pi on
  a plain PSU for mules.
- A Heltec V3 flashed with Meshtastic (flasher.meshtastic.org,  Heltec V3, 
  latest stable, **standard install**, US region). NOT full-erase unless
  recovering a brick.
- The station's role name: FB | RFV | HRV | CHILL | COLD | SPARE (or a custom
  name like PALOMAR for a field-deployed unit).

---

## 1. First contact

Power the station. If using an X728, you may need to press its power button.
But I did not have to because I put in the jumper for auto-on. Remember to
remove the charge-control jumper before putting in the batteries.

Give it ~90 s to boot and join a network, then from your Mac or lesser computer:

    ssh <user>@<hostname>.local

If `.local` won't resolve, get grumpy and then find the IP in your router's 
DHCP client list and `ssh <user>@<ip>`. 
Pi MACs start with b8:27:eb / dc:a6:32 / e4:5f:01 / 2c:cf:67 (now I know)

**If it won't connect at all**, it's almost always the network, not the Pi:
- A plain USB-A-to-USB-C cable might be **power only** (ask me how I know) 
  and it might not give a network link and gives no serial console unless 
  USB gadget mode was pre-configured (it wasn't on a standard card). 
  Do not try to SSH "over USB".
- On a new site the Pi only knows your **home** WiFi. It won't join a different
  network. Fixes, easiest first:
  - **Ethernet cable** from the site router's LAN port, instant DHCP lease.
  - **Phone hotspot** named/passworded **identically to your home WiFi** the
    Pi joins it then SSH in then add the site WiFi (step 4).
  - **Monitor + USB keyboard** (Pi 4 = micro-HDMI) console login.

---

## 2. System update + timezone (UTC is mandatory)

    sudo apt update && sudo apt full-upgrade -y
    sudo timedatectl set-timezone UTC
    date                                # confirm UTC

Every timestamp in the data pipeline assumes UTC. 
Do not skip this. 
Ask me how I know.

---

## 3. Packages + I2C (for the X728 fuel gauge/RTC)

    sudo apt install -y python3-venv python3-pip git i2c-tools sqlite3
    sudo raspi-config nonint do_i2c 0   # enable I2C
    # (reboot later; or `sudo reboot` now if i2cdetect shows nothing)

Acceptance check for the X728 stack (after I2C enabled + reboot):

    i2cdetect -y 1
    # want to see 0x36 (MAX17048 fuel gauge) and 0x68 (DS1307 RTC)
    dmesg | grep -i volt                # empty = clean power, no brownouts!

`0x36` present proves the Pi to X728 GPIO stack seated correctly. Bench mules on a
plain PSU won't show these and that is totally ok don't get worried. 

---

## 4. Networking: Ethernet + WiFi + failover

Doctrine: **Ethernet preferred** (robust, survives hostile con WiFi), WiFi as
fallback, home WiFi kept so the station reconnects when it comes back to HQ.
NetworkManager stores multiple profiles and picks whatever is available. Adding
a network does NOT remove the others.

Add the site WiFi (quote SSID/password, use single quotes if they contain
spaces or shell characters like `$`):

    sudo nmcli device wifi connect 'SiteSSID' password 'sitepassword'
    nmcli connection show               # confirm home + site + wired all listed
    nmcli device status                 # wlan0 should say 'connected'

Optional: make Ethernet strongly preferred:

    sudo nmcli connection modify <wired-conn-name> connection.autoconnect-priority 100

**[ON-SITE] Test WiFi failover before you leave:** unplug Ethernet, wait ~15 s,
confirm still reachable (`nmcli device status` should keep wlan0 connected), and
check upstream:

    ping -c 3 1.1.1.1                   # clean = WiFi has real internet! Yay!

Then re-plug Ethernet if leaving it wired.

---

## 5. **[ON-SITE]** Tailscale to give remote access through any NAT

Home 5G/cellular backhaul is almost always CGNAT. Without a tunnel you can only
reach the station from inside its LAN, and lose it the moment you leave. Tailscale
punches through. **Set this up while physically present and TEST it before driving
away because it is miserable to fix remotely.**

On the station:

    curl -fsSL https://tailscale.com/install.sh | sh
    sudo tailscale up                   # follow the auth link; log in (e.g. GitHub)
    tailscale ip -4                     # note this 100.x.y.z address

On your Mac (once, if not already there):

    brew install tailscale && sudo tailscale up
    # log in with the SAME account/tailnet as the station

**Test from the Mac while still on-site:**

    ssh <user>@100.x.y.z                # the station's tailscale ip
    # or, with MagicDNS on:  ssh <user>@<hostname>

That address is now permanent and reachable from anywhere, on Ethernet or WiFi,
at home or at a con. This is the "remote hands" capability the fleet depends on.

---

## 6. Clone the repo + Python venv

    cd ~ && mkdir -p Meshtastic && cd Meshtastic
    git clone https://github.com/OpenResearchInstitute/sending-stones.git
    cd sending-stones
    python3 -m venv ~/mesh
    source ~/mesh/bin/activate
    pip install meshtastic==2.7.11 pyyaml pypubsub
    echo 'source ~/mesh/bin/activate' >> ~/.bashrc   # auto-activate on login

Pin meshtastic to the fleet version (2.7.11) so every station speaks the same
lingo. Later updates are a deliberate migration, not a surprise.

---

## 7. Name the radios + set region AND preset (BOTH radios)

For a two-radio station, cohort A = LongFast (default), cohort B = ShortTurbo.
The ShortTurbo set is a SEPARATE command and is easy to miss and a missed preset
leaves cohort B silently running LongFast (a duplicate A radio), which corrupts
the entire ShortTurbo dataset invisibly.

Cohort A radio (ttyUSB0) — name, region, confirm LongFast:

    meshtastic --set-owner "Stone <Name> A" --set-owner-short "<CODE>A" --port /dev/ttyUSB0
    meshtastic --set lora.region US --port /dev/ttyUSB0
    # LongFast is the default preset; no preset set needed for A

Cohort B radio (ttyUSB1) — name, region, AND set ShortTurbo:

    meshtastic --set-owner "Stone <Name> B" --set-owner-short "<CODE>B" --port /dev/ttyUSB1
    meshtastic --set lora.region US --port /dev/ttyUSB1
    meshtastic --set lora.modem_preset SHORT_TURBO --port /dev/ttyUSB1   # <-- easy to miss!

**MANDATORY verification! Make it Abraxas3d-proof! both radios, region AND preset:**

    # region on both (must be 1 = US, not 0 = UNSET):
    meshtastic --get lora.region --port /dev/ttyUSB0    # want: 1
    meshtastic --get lora.region --port /dev/ttyUSB1    # want: 1

    # preset/bandwidth confirms which modulation each radio is ACTUALLY on:
    meshtastic --get lora --port /dev/ttyUSB0 | grep -E "bandwidth|spread_factor"
    #   cohort A: want bandwidth 250, spread_factor 11  (LongFast)
    meshtastic --get lora --port /dev/ttyUSB1 | grep -E "bandwidth|spread_factor"
    #   cohort B: want bandwidth 500, spread_factor 7   (ShortTurbo)

If cohort B shows bandwidth 250 / SF 11, the ShortTurbo set was MISSED and the
radio is running LongFast. Re-run the modem_preset command and re-verify.

## 7b. Post-setup verification gate (run on EVERY station before deploying)

Three silent-misconfiguration bugs have bitten this fleet, all invisible until
the station produces wrong/no data. Run this block on every station. 

    # both radios on US band:
    meshtastic --get lora.region --port /dev/ttyUSB0    # 1
    meshtastic --get lora.region --port /dev/ttyUSB1    # 1
    # A is LongFast, B is ShortTurbo:
    meshtastic --get lora --port /dev/ttyUSB0 | grep bandwidth   # 250
    meshtastic --get lora --port /dev/ttyUSB1 | grep bandwidth   # 500
    # by-path serials distinct (two entries):
    ls /dev/serial/by-path/ | grep -c usb-0                       # 2 (for two radios)
    # config has unique station_id and slot:
    grep -E "station_id|slot:" ~/Meshtastic/sending-stones/code/config.yaml

A one-minute check here prevents an undetectable-until-analysis data disaster
at the event.

---

## 8. config.yaml

    cd ~/Meshtastic/sending-stones/code
    cp config.example.yaml config.yaml
    nano config.yaml

Per-station edits:
- `station_id:` the role code (e.g. COLD)
- `cohorts:` keep **only the cohorts you have radios for**. A one-radio
  monitoring node has just cohort A — **delete the cohort B block**, or the
  logger will hang/retry forever trying to open a nonexistent `CHANGE_ME_B`
  serial device.
- `cohorts.A.serial:` the by-id path from step 7
- `tx_enabled: false` for a monitoring/RX-only node (no probe transmission).
  `true` only when running probes with a controlled transmitter.
- `capture_trials.enabled: false` for a solo node.
- `db_path:` use a writable path — **`/home/<user>/mesh_pdr_{station_id}.sqlite`**,
  NOT `/data/...` (that root path doesn't exist / needs root and will crash).

Minimal one-radio monitoring config:

    station_id: COLD
    slot: 2
    slot_width_s: 12
    minute_period_s: 60
    cohorts:
      A:
        preset: LongFast
        serial: /dev/serial/by-id/usb-Silicon_Labs_CP2102_USB_to_UART_Bridge_Controller_0001-if00-port0
    tx_enabled: false
    jitter_max_s: 3.0
    payload:
      short_len: 20
      long_len: 180
    capture_trials:
      enabled: false
      roster: [FB, RFV, HRV, CHILL, COLD]
      every_min: 10
      cohort_alternate: false
      threeway:
        enabled: false
        every_nth_trial: 7
    census_period_s: 600
    util_period_s: 60
    db_path: /home/abraxas3d/mesh_pdr_{station_id}.sqlite
    log_level: INFO

Here is a two-radio config.yaml file:

```
station_id: FB
slot: 0                    # FB's transmit slot; each station unique 0..N-1
slot_width_s: 12
minute_period_s: 60

cohorts:
  A:
    preset: LongFast
    serial: /dev/serial/by-path/platform-fd500000.pcie-pci-0000:01:00.0-usb-0:1.3:1.0-port0
  B:
    preset: ShortTurbo
    serial: /dev/serial/by-path/platform-fd500000.pcie-pci-0000:01:00.0-usb-0:1.4:1.0-port0

tx_enabled: true           # FB transmits probes (this is an experiment station, not a passive monitor)
jitter_max_s: 3.0

payload:
  short_len: 20
  long_len: 180

capture_trials:
  enabled: false           # keep off for the first bench bring-up; enable once round-trip works
  roster: [FB, RFV, HRV, CHILL, COLD]
  every_min: 10
  cohort_alternate: false
  threeway:
    enabled: false
    every_nth_trial: 7

census_period_s: 600
util_period_s: 60

db_path: /home/abraxas3d/mesh_pdr_{station_id}.sqlite
log_level: INFO
```

---

## 9. Verify the code before running

    cd ~/Meshtastic/sending-stones/code
    python3 -m py_compile monitor_rx.py && echo "syntax OK"
    python3 -c "import monitor_rx; print('methods:', \
      hasattr(monitor_rx.Monitor,'on_receive'), \
      hasattr(monitor_rx.Monitor,'on_established'))"

Want `syntax OK` and both methods `True`. `on_established` present = the
NodeDB-replay gate is in this checkout (drops connect-time replay so only live
receptions are logged). py_compile catches syntax and the hasattr check catches a
method accidentally de-indented out of the class.

---

## 10. First-light aperture scan (capture it)

    meshtastic --nodes | tee ~/<name>-firstlight-nodes.txt

Save this becuase the node list + SNR distribution characterizes the site's aperture.
High/clear sites show much stronger SNR (near 0 dB) than low/cluttered ones
(near -20 dB, the decode floor). Commit to `data/bench/` as a site record.

---

## 11. Start the logger (detached, unbuffered)

    cd ~/Meshtastic/sending-stones/code
    nohup python3 -u monitor_rx.py --config config.yaml > ~/<name>-soak.log 2>&1 &
    echo $! > ~/<name>.pid
    sleep 90 && sqlite3 ~/mesh_pdr_<STATION_ID>.sqlite \
      "SELECT COUNT(*) rx FROM rx_log; SELECT COUNT(*) util FROM utilization;"

The `-u` (unbuffered) is mandatory for a backgrounded logger. Without it stdout
buffers and the log looks dead even while it's working. Non-zero counts = it's
logging. Note: on a quiet channel `rx` grows slowly; `util` ticks up ~1/min
regardless (it polls the local radio), so a climbing `util` alone proves the
loop is alive.

Stop it later with `kill $(cat ~/<name>.pid)`.

---

## 12. Leaving / handoff checklist

Before you walk away from an on-site deployment, confirm:
- [ ] Reachable over Tailscale from the Mac (`ssh <user>@100.x.y.z`)
- [ ] wlan0 connected (WiFi fallback proven) AND/OR Ethernet plugged (preferred)
- [ ] `ping 1.1.1.1` clean (upstream exists for the tunnel)
- [ ] logger running (`pgrep -af monitor_rx`) and DB row counts climbing
- [ ] first-light `--nodes` scan saved
- [ ] radio named, region US, OLED shows the station name

Everything after step 5 can be redone remotely over Tailscale, so you can
get power + network + Tailscale working on-site, then finish the
software from home!

---

## Known gotchas (learned the hard way)

- **USB cable might not give you a network.**
- **Wrong-WiFi silence.** A Pi at a new site with only home credentials boots
  fine and joins nothing and is invisible. Ethernet or hotspot-mimic to get in.
- **`db_path: /data/...`** crashes (no such dir / needs root). Use home dir.
- **Leftover `CHANGE_ME_B` cohort** makes the logger retry a dead serial device
  forever. Delete unused cohorts. Put them back in when you get a second radio.
- **`fromId` vs `from_id`**, **SQLite thread ownership**, and **NodeDB replay**
  are all handled in the current `monitor_rx.py`/`db.py` just don't regress
  them. The replay gate (`on_established` → `self.live`) is why the DB doesn't
  fill with stale connect-time replay packets.
- **Bad SD cards** fail imaging randomly ("some work, some don't"). Verify-on-
  write, and retire any card that fails a clean re-image twice then use a spare.
- **X728 power** goes IN via the X728's USB-C, not the Pi's own port, once the
  board is installed.
- **Possibly avoid full-erase** flash the Heltec with the instructions from the
  event because there might be bugs or weirdness. Ask around and research before
  just doing the usual standard firmware updates. 

- **Missed ShortTurbo preset on cohort B!** The `--set lora.modem_preset
  SHORT_TURBO` on ttyUSB1 is a separate step from region and is easy to skip on
  some stations. A cohort-B radio left on default LongFast is a duplicate A radio
  mislabeled as B — it lands on the LongFast frequency, so it hears the other
  mis-set B radios (and the real LongFast world) but NOT the correctly-set
  ShortTurbo stations. Symptom: the cohort-B delivery matrix splits into two
  islands (correctly-set stations vs mis-set stations), each ~1.00 internally,
  0.00 across. Verify bandwidth 500 / SF 7 on every cohort-B radio before
  deploying. (Found: RFV, HRV, SPARE shipped LongFast-on-B; FB, CHILL were
  correct. Lab baseline caught it.)

## Useful sqlite commands

### how many distinct nodes so far?
sqlite3 ~/mesh_pdr_COLD.sqlite "SELECT COUNT(DISTINCT from_id) FROM rx_log WHERE from_id IS NOT NULL;"

### the SNR distribution — is the mountain really hearing strong?
sqlite3 ~/mesh_pdr_COLD.sqlite "SELECT ROUND(snr) s, COUNT(*) FROM rx_log WHERE snr IS NOT NULL GROUP BY s ORDER BY s;"

### port mix — what kind of traffic
sqlite3 ~/mesh_pdr_COLD.sqlite "SELECT portnum, COUNT(*) FROM rx_log GROUP BY portnum ORDER BY 2 DESC;"

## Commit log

2026-08-26 Sending Stones: initial design, station code, BOM (Rev B.1)
2026-08-27 raker from RF Village discord recommends Geekworm X728 so it's in the BOM specifically.
2026-09-03 Update BOM.md
    adjusted BOM Cost
2026-09-06 First light for stone-cold receiver monitor temporarily on Palomar Mountain
2026-09-18 united the tx and rx so that threads can pull it all together and we can transmit and receive at the same time. Needed a lot of help with this! thank you to RF Village and ORI folks.
2026-09-20 slot_number * 12 = 60s for the jitter has a bug. 0, 1, 2, 3, and 4 all work ok, but 5 * 12 is 60 and this pushes that radio probe into the next 60 second time period.
2026-10-08 hoo boy more bugs fixed. This time we fixed the wifi watchdog because it was nuking the station in a loop when ethernet is attached.
2026-10-08 updated the watchdog timer echo statement so it wasn't stale
2026-10-09 Drafting a layout for a sending stone base plate, ground planes for antennas, and case blocks for the Heltecs. This is intended to allow for decoration and personalization as well as protection and a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
    [sending-stones-case.scad]
2026-10-09 Added the base layer back into the default visualization.
    [sending-stones-case.scad]
